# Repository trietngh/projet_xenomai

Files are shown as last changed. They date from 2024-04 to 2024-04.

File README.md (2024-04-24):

# Dumber

Depot du projet de temps reel 4eme année au departement GEI de l'INSA Toulouse.

## Repertoires
- hardware : contient les plans pour la partie mecanique du robot et de son chargeur, ainsi que les plans de conception des PCB du robot, du chargeur, de l'adaptateur Xbee pour la raspberry  et les plans des CAP du robot
- software: rassemble les parties logicielles du robot, du chargeur, les bibliotheques et superviseur coté raspberry et l'interface Web
- doc: contient les sujets de TD et TP
- aruco_markers: Script de generation des tags (aruco) utilisés sur les robots

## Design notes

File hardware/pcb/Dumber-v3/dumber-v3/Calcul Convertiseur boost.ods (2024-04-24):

Vout | 5
Vin | 3
Vsw | 0,5
Vdiode | 0,5
Fsw | 1600000
L1 | 0,00001
R2 | 13300
R1 | 40765,0406504065
DC | 0,6
Iload(objectif) | 1,5
Iind(Avg) | 3,75
Iripple | 0,09375
Isw | 3,796875
Iload(calc) | 1,5
Rled | 200
Cf | 6,50719483232995E-10

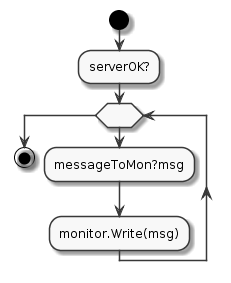
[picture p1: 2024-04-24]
doc/sujets/tex/rapport_etudiant/figures-pdf/th_sendToMon.png

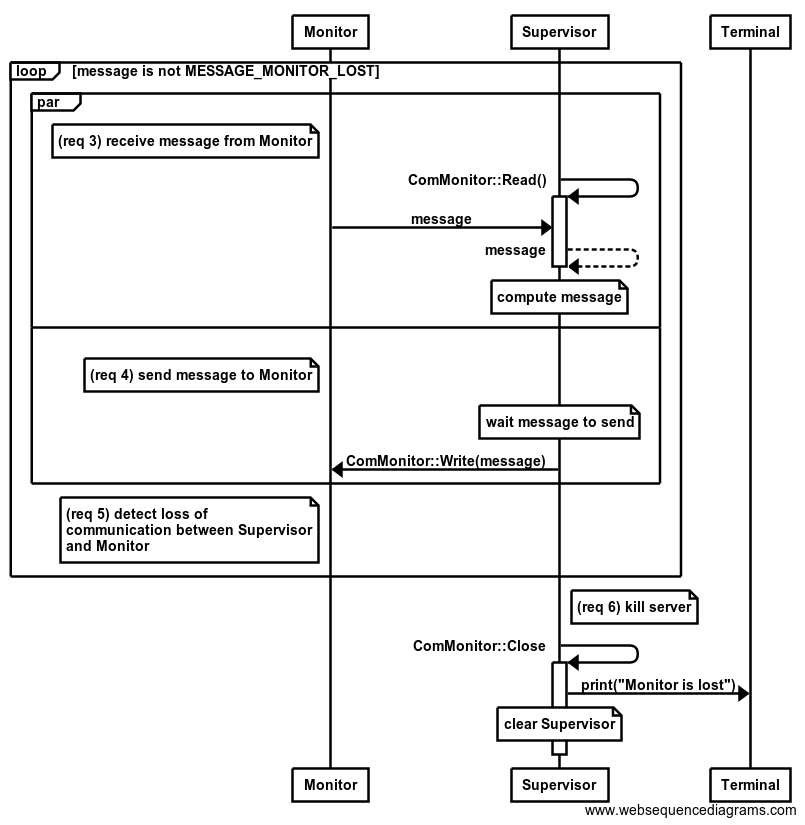
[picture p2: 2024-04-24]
doc/sujets/tex/specifications/seq_req/req3-6.png

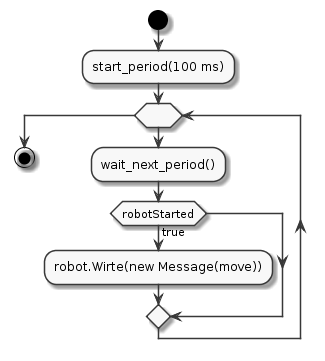
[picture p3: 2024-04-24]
doc/sujets/tex/conception/figures_pdf/activity/th_move.png

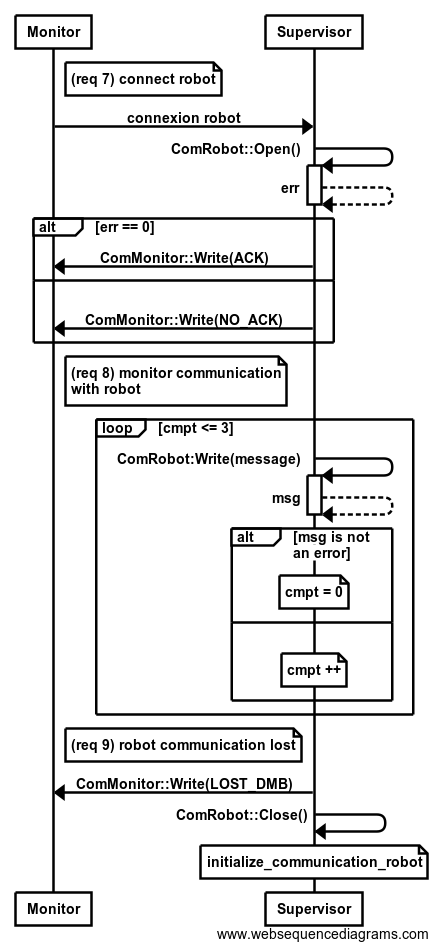
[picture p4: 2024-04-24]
doc/sujets/tex/specifications/seq_req/req7-9.png

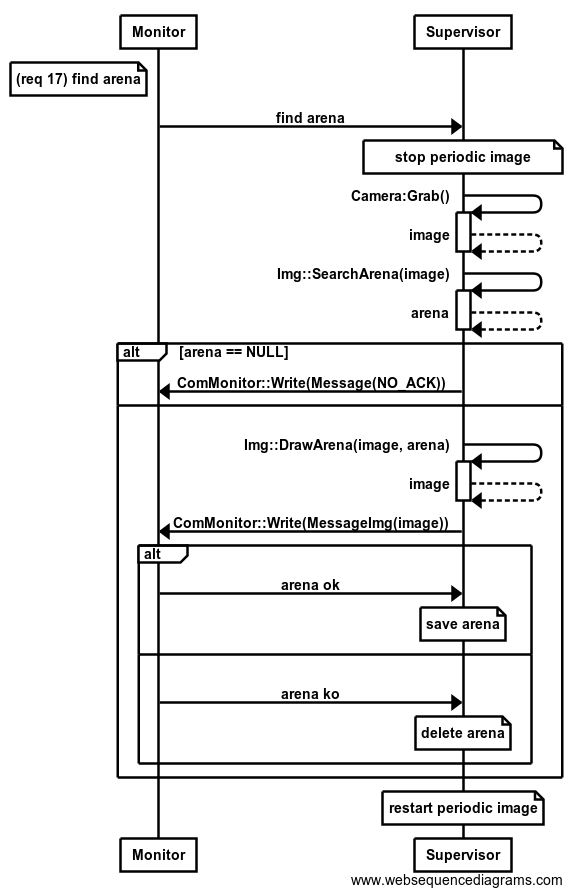
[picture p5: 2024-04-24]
doc/sujets/tex/specifications/seq_req/req17.png

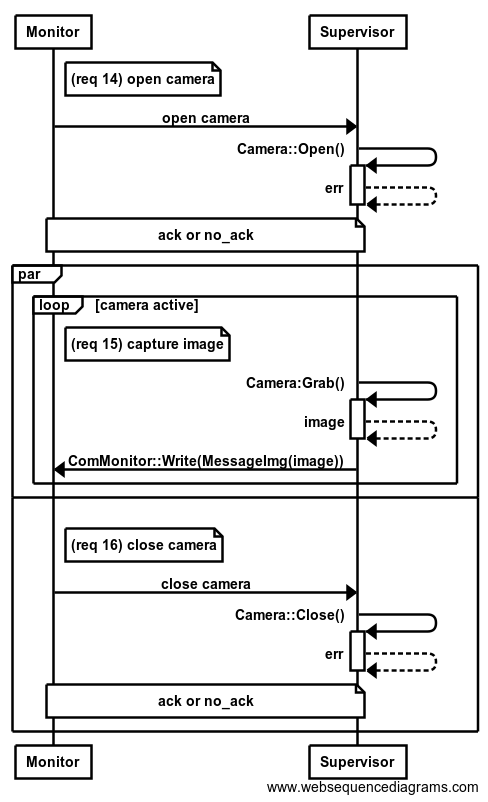
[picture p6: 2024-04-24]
doc/sujets/tex/specifications/seq_req/req14-16.png

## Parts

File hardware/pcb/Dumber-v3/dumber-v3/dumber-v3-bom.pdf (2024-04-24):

Source: /home/dimercur/Travail/git/dumber/hardware/pcb/Dumber-v3/dumber-v3/dumber-v3.kicad_sch Date: lun. 04 sept. 2023 10:56:20
Tool: Eeschema 7.0.7
Generator:/app/share/kicad/plugins/bom_csv_grouped_by_value.py
Component Count:70
Collated Components:
Item | Qty | Reference(s) | Value | LibPart | Footprint | Datasheet DNP
1 | 1 BT1 | Li-ION | Device:Battery_Cell | INSA:Battery-14500 | ~
2 | 2 C1, C4 | 10nF Device:C | Capacitor_SMD:C_0805_2012Metric ~
3 | 1 C2 | 68nF Device:C | Capacitor_SMD:C_0805_2012Metric ~
4 | 1 C3 | 100µF Device:C | Capacitor_SMD:C_1210_3225Metric ~
5 | 1 C5 | 2,20µF Device:C | Capacitor_SMD:C_0805_2012Metric ~
6 | 2 C6, C11 | 10µF Device:C | Capacitor_SMD:C_0805_2012Metric ~
7 | 4 C7, C12, C13, C22 | 1µF Device:C | Capacitor_SMD:C_0805_2012Metric ~
8 | 1 C8 | 650pF Device:C | Capacitor_SMD:C_0805_2012Metric ~
9 | 1 C9 | 100pF Device:C | Capacitor_SMD:C_0805_2012Metric ~
10 | 1 C10 | 10µF Device:C | Capacitor_SMD:C_1210_3225Metric ~
11 | 2 C14, C15 | 470nF Device:C | Capacitor_SMD:C_0805_2012Metric ~
12 | 4 C16, C17, C18, C19 | 100nF Device:C | Capacitor_SMD:C_0805_2012Metric ~
13 | 1 C21 | 1nF Device:C | Capacitor_SMD:C_0805_2012Metric ~
14 | 1 D1 | PMEG2020CPA | Device:D_Dual_CommonCathode_AAK_Parallel INSA:Nexperia_SOT-1061 | ~
15 | 1 D2 | FM5818-W | Device:D_Schottky | Diode_SMD:D_SMA | ~
16 | 3 H1, H2, H3 | MountingHole | Mechanical:MountingHole | MountingHole:MountingHole_3.2mm_M3_ISO14580 ~
17 | 2 J1, J2 | Conn_02x03_Odd_Even Connector_Generic:Conn_02x03_Odd_Even | Connector_IDC:IDC-Header_2x03_P2.54mm_Vertical ~
18 | 1 J3 | Conn_02x05_Odd_Even Connector_Generic:Conn_02x05_Odd_Even | Connector_PinHeader_1.27mm:PinHeader_2x05_P1.27mm_Horizontal ~
19 | 1 J4 | TE 1-84982-0 | Connector_Generic:Conn_01x10 | INSA:TE 1-84982-0 | ~
20 | 1 L1 | 10µH Device:L | Inductor_SMD:L_Bourns_SRP7028A_7.3x6.6mm ~
21 | 1 L2 | 5,6µH | Device:L | Inductor_SMD:L_1812_4532Metric | ~
22 | 2 M1, M2 | Motor | Insa:Motor | INSA:Motor Pololu HPCB with encoder
23 | 1 P1 | USB_C_Plug_GCT_USB4125 Insa:USB_C_Plug_GCT_USB4125 | INSA:USB_C_Receptacle_GCT_USB4125 https://www.usb.org/sites/default/files/documents/usb_type-c.zip
24 | 2 Q1, Q2 | PMN52XP | Insa:PMN52XP | Package_SO:TSOP-6_1.65x3.05mm_P0.95mm~
25 | 8 R1, R2, R4, R20, R24, R27, R28, R29 | 100K Device:R | Resistor_SMD:R_0805_2012Metric | ~
26 | 5 R3, R5, R7, R17, R18 | 1K Device:R | Resistor_SMD:R_0805_2012Metric | ~
27 | 2 R6, R26 | 10K Device:R | Resistor_SMD:R_0805_2012Metric | ~
28 | 1 R8 | 47K Device:R | Resistor_SMD:R_0805_2012Metric | ~
29 | 1 R9 | 470 Device:R | Resistor_SMD:R_0805_2012Metric | ~
30 | 1 R10 | 40,2K Device:R | Resistor_SMD:R_0805_2012Metric | ~
31 | 1 R11 | 13,3K Device:R | Resistor_SMD:R_0805_2012Metric | ~
32 | 2 R12, R14 | 15K Device:R | Resistor_SMD:R_0805_2012Metric | ~
33 | 1 R13 | 300 Device:R | Resistor_SMD:R_0805_2012Metric | ~
34 | 1 R19 | 150K Device:R | Resistor_SMD:R_0805_2012Metric | ~
35 | 1 R25 | 10R Device:R | Resistor_SMD:R_0805_2012Metric | ~
36 | 1 SW1 | SW_Push | Switch:SW_Push | Button_Switch_SMD:Panasonic_EVQPUJ_EVQPUA ~
37 | 1 U1 | XBEE-3 | Insa:XBEE-3 | INSA:XBEE-3-TH
38 | 1 U2 | STM32F071CBTx | MCU_ST_STM32F0:STM32F071CBTx | Package_QFP:LQFP-48_7x7mm_P0.5mm http://www.st.com/st-web-ui/static/active/en/resource/technical/document/datasheet/DM00098745.pdf
39 | 1 U3 | LTC2954-2 | Insa:LTC2954-2 | Package_TO_SOT_SMD:SOT-23-8
40 | 1 U4 | L6924U | Insa:L6924U | INSA:L6924UTR
41 | 1 U5 | LM2731XMF | Regulator_Switching:LM2731XMF | Package_TO_SOT_SMD:SOT-23-5 | http://www.ti.com/lit/ds/symlink/lm2731.pdf
42 | 1 U6 | AP2206 | Regulator_Linear:TC1186 | Package_TO_SOT_SMD:SOT-23-5 | http://ww1.microchip.com/downloads/en/DeviceDoc/21350E.pdf
43 | 1 U7 | A3909 | Insa:A3909 | Package_SO:SSOP-10_3.9x4.9mm_P1.00mm

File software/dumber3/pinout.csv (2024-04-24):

Position | Name | Type | Signal | Label | AF0 | AF1 | AF2 | AF3 | AF4 | AF5 | AF6
1 | PC0 | I/O | LPTIM1_IN1 | ENC_PHA_GAUCHE | LPTIM1_IN1 |  | EVENTOUT |  |  |  | LPUART1_RX
2 | PC13-ANTI_TAMP | I/O
3 | PC14-OSC32_IN | I/O
4 | PC15-OSC32_OUT | I/O
5 | PH0-OSC_IN | I/O
6 | PH1-OSC_OUT | I/O
7 | NRST | Reset
8 | VSSA | Power
9 | VDDA | Power
10 | PA0 | I/O | ADC_IN0 | BATTERY_SENSE |  | LPTIM1_IN1 | TIM2_CH1 |  | USART2_CTS | TIM2_ETR
11 | PA1 | I/O | TIM2_CH2 | PWM_B_GAUCHE | EVENTOUT | LPTIM1_IN2 | TIM2_CH2 | I2C1_SMBA | USART2_DE/USART2_RTS | TIM21_ETR
12 | PA2 | I/O | TIM21_CH1 | ENC_PHA_DROIT | TIM21_CH1 |  | TIM2_CH3 |  | USART2_TX |  | LPUART1_TX
13 | PA3 | I/O | TIM21_CH2 | ENC_PHB_DROIT | TIM21_CH2 |  | TIM2_CH4 |  | USART2_RX |  | LPUART1_RX
14 | PA4 | I/O |  |  | SPI1_NSS | LPTIM1_IN1 |  |  | USART2_CK
15 | PA5 | I/O | LPTIM1_IN2 | ENC_PHB_GAUCHE | SPI1_SCK | LPTIM1_IN2 | TIM2_ETR |  |  | TIM2_CH1
16 | PA6 | I/O |  |  | SPI1_MISO | LPTIM1_ETR |  |  | LPUART1_CTS |  | EVENTOUT
17 | PA7 | I/O |  |  | SPI1_MOSI | LPTIM1_OUT |  |  | USART2_CTS |  | EVENTOUT
18 | PB0 | I/O | TIM2_CH3 | PWM_A_DROIT | EVENTOUT | SPI1_MISO |  |  | USART2_DE/USART2_RTS | TIM2_CH3
19 | PB1 | I/O | TIM2_CH4 | PWM_B_DROIT | USART2_CK | SPI1_MOSI |  |  | LPUART1_DE/LPUART1_RTS | TIM2_CH4
20 | PB2 | I/O |  |  |  |  | LPTIM1_OUT
21 | PB10 | I/O | LPUART1_TX |  |  |  | TIM2_CH3 |  |  |  | LPUART1_TX
22 | PB11 | I/O | LPUART1_RX |  | EVENTOUT |  | TIM2_CH4 |  |  |  | LPUART1_RX
23 | VSS | Power
24 | VDD | Power
25 | PB12 | Output | GPIO_Output | LED_ROUGE | SPI1_NSS |  |  |  |  |  | EVENTOUT
26 | PB13 | Output | GPIO_Output | LED_ORANGE | SPI1_SCK |  | RCC_MCO |  |  | TIM21_CH1 | LPUART1_CTS
27 | PB14 | Output | GPIO_Output | LED_VERTE | SPI1_MISO |  | RTC_OUT_ALARM/RTC_OUT_CALIB |  |  | TIM21_CH2 | LPUART1_DE/LPUART1_RTS
28 | PB15 | Output | GPIO_Output | SHUTDOWN_ENCODERS | SPI1_MOSI |  | RTC_REFIN
29 | PA8 | I/O | TIM2_CH1 | PWM_A_GAUCHE | RCC_MCO |  | LPTIM1_IN1 | EVENTOUT | USART2_CK | TIM2_CH1
30 | PA9 | I/O |  |  | RCC_MCO | I2C1_SCL |  |  | USART2_TX
31 | PA10 | I/O |  |  |  | I2C1_SDA |  |  | USART2_RX
32 | PA11 | I/O |  |  | SPI1_MISO |  | EVENTOUT |  | USART2_CTS | TIM21_CH2
33 | PA12 | I/O |  |  | SPI1_MOSI |  | EVENTOUT |  | USART2_DE/USART2_RTS
34 | PA13 | I/O | SYS_SWDIO |  | SYS_SWDIO | LPTIM1_ETR |  |  |  |  | LPUART1_RX
35 | VSS | Power
36 | VDD | Power
37 | PA14 | I/O | SYS_SWCLK |  | SYS_SWCLK | LPTIM1_OUT |  | I2C1_SMBA | USART2_TX |  | LPUART1_TX
38 | PA15 | I/O |  |  | SPI1_NSS |  | TIM2_ETR | EVENTOUT | USART2_RX | TIM2_CH1
39 | PB3 | I/O | GPIO_EXTI3 | BUTTON_SENSE | SPI1_SCK |  | TIM2_CH2 |  | EVENTOUT
40 | PB4 | I/O | GPIO_EXTI4 | USB_SENSE | SPI1_MISO |  | EVENTOUT
41 | PB5 | I/O |  |  | SPI1_MOSI |  | LPTIM1_IN1 | I2C1_SMBA
42 | PB6 | Input | GPIO_Input | CHARGER_ST2 | USART2_TX | I2C1_SCL | LPTIM1_ETR |  |  | TIM21_CH1
43 | PB7 | Input | GPIO_Input | CHARGER_ST1 | USART2_RX | I2C1_SDA | LPTIM1_IN2
44 | BOOT0 | Boot
45 | PB8 | Output | GPIO_Output | SHUTDOWN_5V |  |  |  |  | I2C1_SCL
46 | PB9 | Output | GPIO_Output | SHUTDOWN |  |  | EVENTOUT |  | I2C1_SDA
47 | VSS | Power
48 | VDD | Power

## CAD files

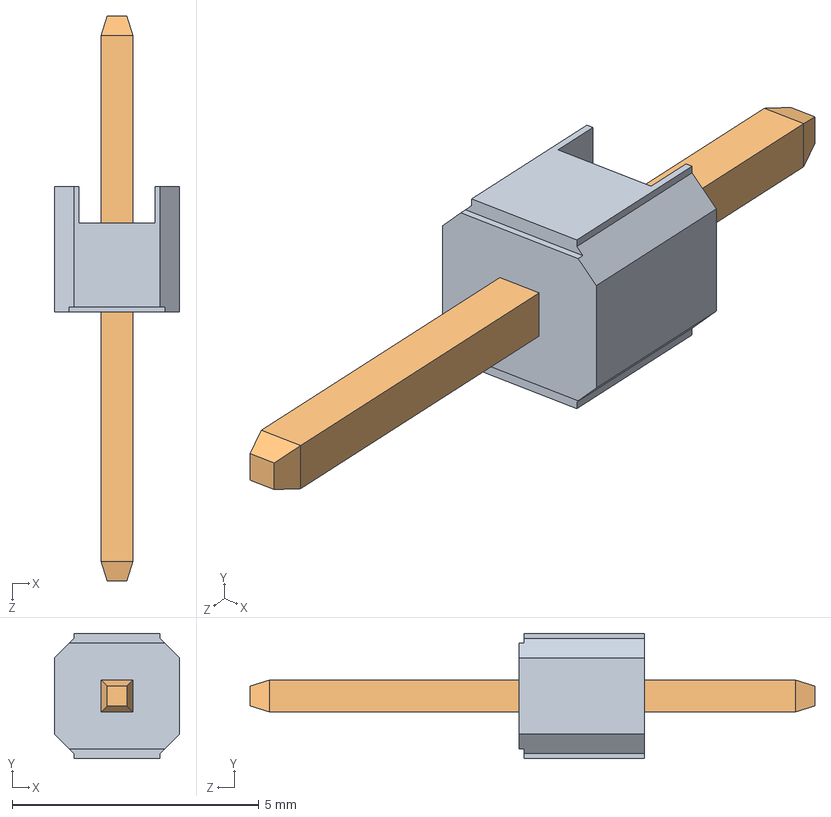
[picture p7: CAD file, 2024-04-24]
hardware/meca/Bibliotheque/headers/2.54_straight-header.SLDASM
2.54 x 2.54 x 11.4 mm
2.54_base
2.54_straight-pin

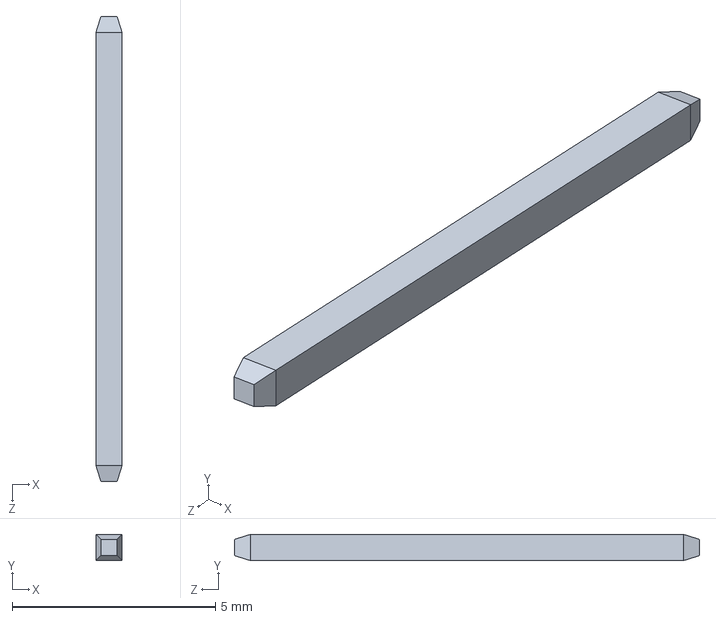
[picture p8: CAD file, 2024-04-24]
hardware/meca/Bibliotheque/headers/2.54_straight-pin.SLDPRT
0.65 x 0.65 x 11.4 mm

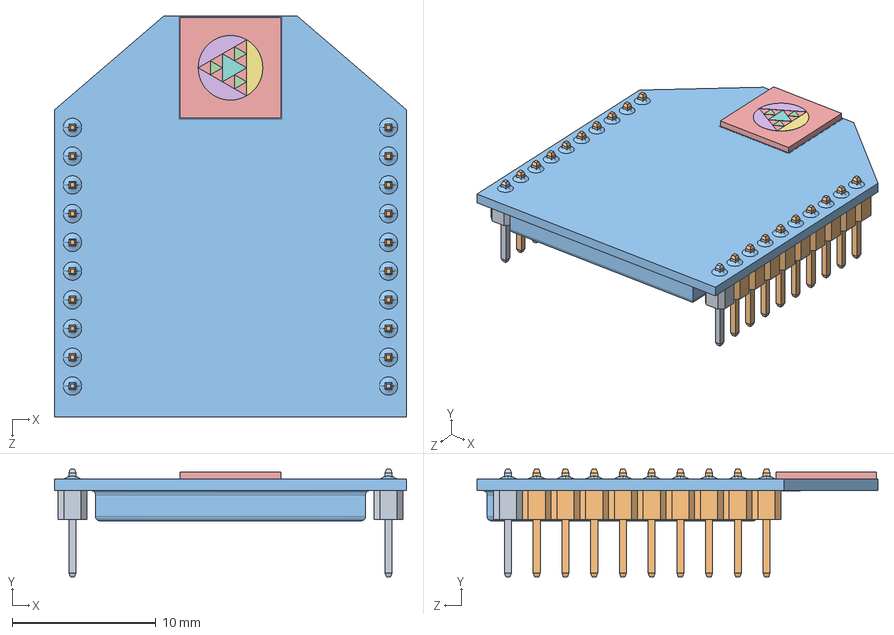
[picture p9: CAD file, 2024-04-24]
hardware/meca/Bibliotheque/XBee Chip.STEP
24.5 x 7.50 x 27.9 mm
User Library-XBee-Chip_XBee-10pin-male_1 x 2
User Library-XBee-Chip_XBee-Chip_1
User Library-XBee-Chip_XBee-Chip-antenna_1

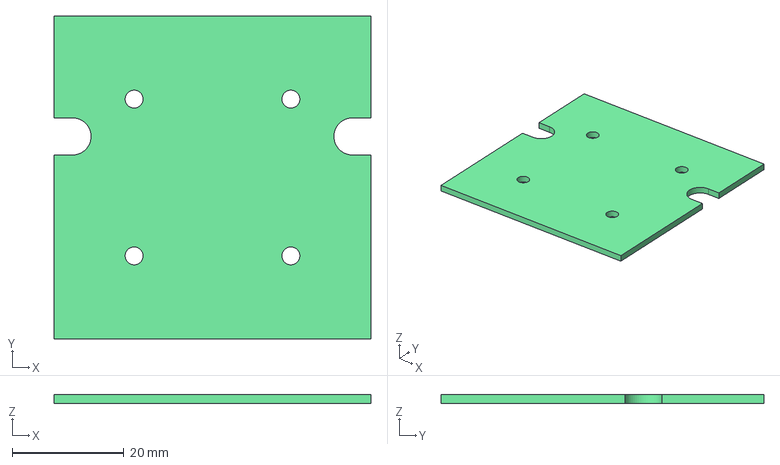
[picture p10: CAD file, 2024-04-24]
hardware/meca/Chargeur/1593K PCB.stp
56.6 x 57.7 x 1.60 mm

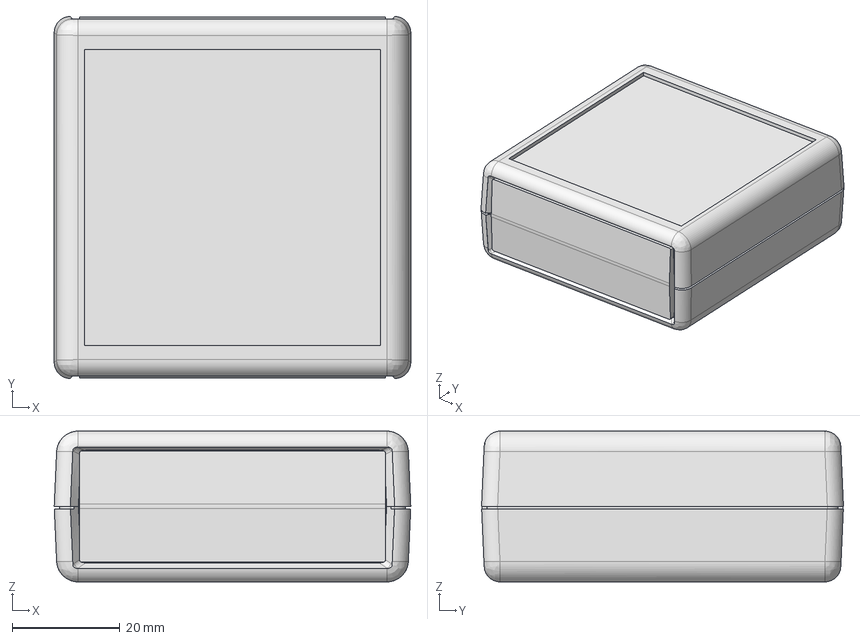
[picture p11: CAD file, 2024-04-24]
hardware/meca/Chargeur/Hammond/1593K.stp
66.2 x 67.2 x 28.0 mm
1593K BOTTOM
1593K Top
1593K-L-P-Q-X-Y Flat endplate x 2
1593K-L-P-Q-X-Y Contoured Endplate x 2
1593K PCB

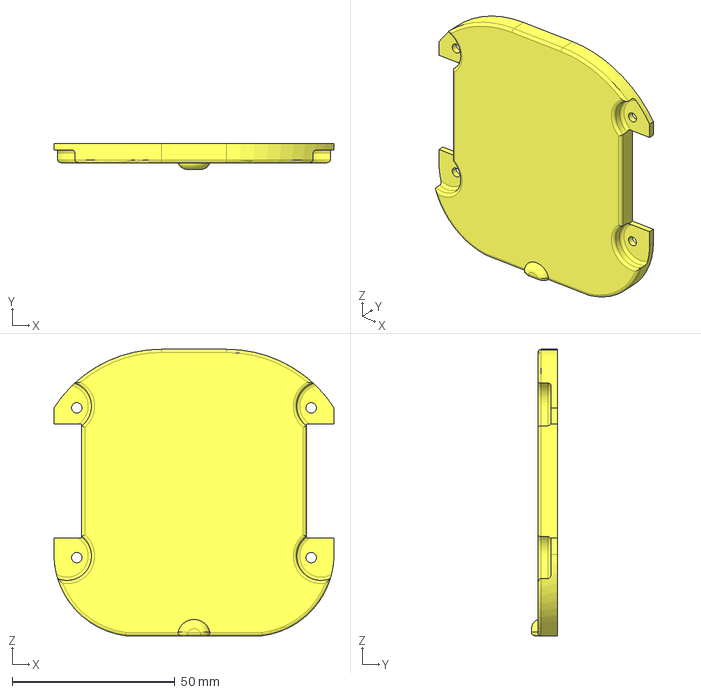
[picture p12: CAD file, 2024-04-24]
hardware/meca/coque_inf.stp
86.0 x 8.00 x 88.0 mm

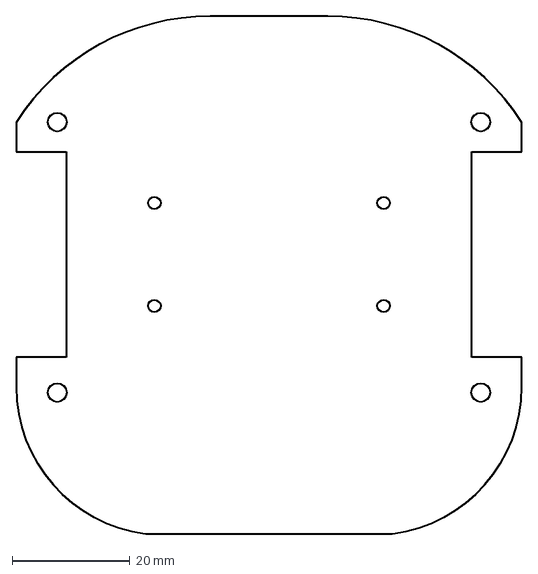
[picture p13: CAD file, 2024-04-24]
hardware/meca/Dumber_2022/export/pcb-tole.dxf
86.0 x 88.0 mm

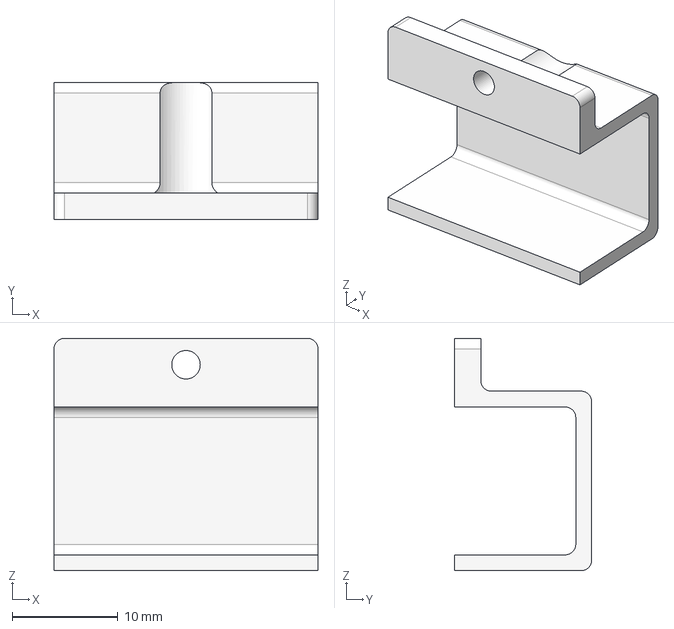
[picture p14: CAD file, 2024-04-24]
hardware/meca/Export/capot.stp
25.0 x 13.0 x 22.0 mm

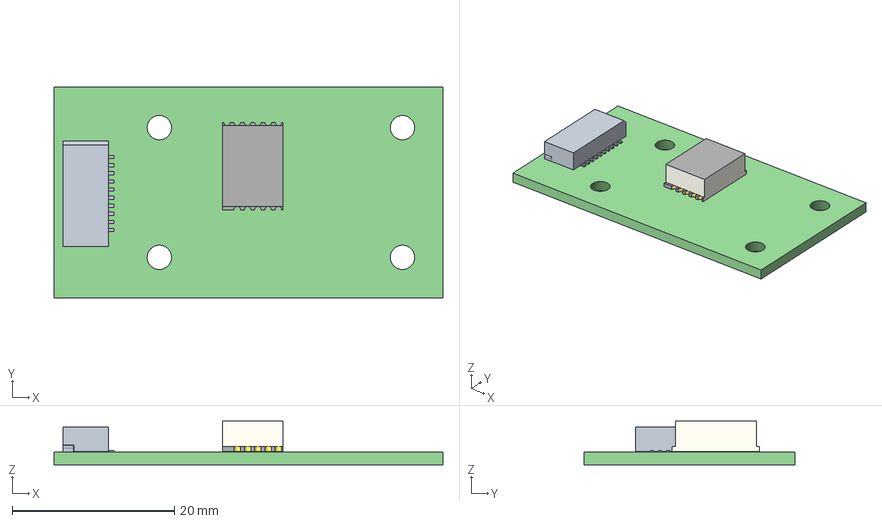
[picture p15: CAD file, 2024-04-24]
hardware/pcb/Dumber-v3/ecran/ecran/ecran.step
48.0 x 26.0 x 5.40 mm
ecran PCB

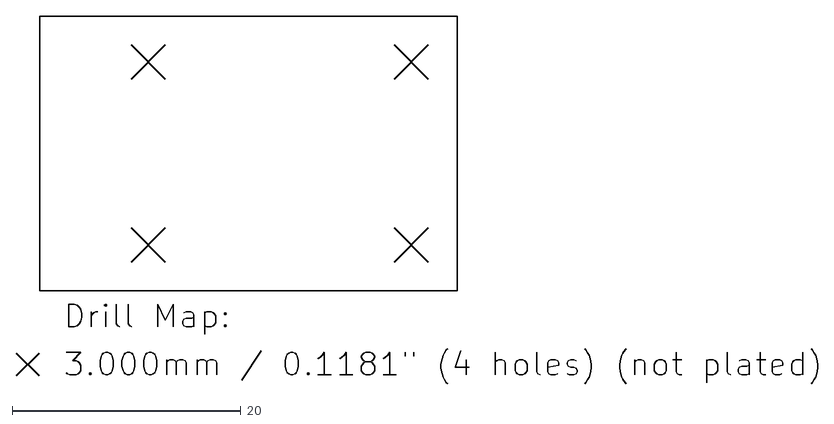
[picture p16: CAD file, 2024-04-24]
hardware/pcb/Dumber-v3/ecran/ecran/Gerber/ecran-NPTH-drl_map.dxf
70.1 x 32.1

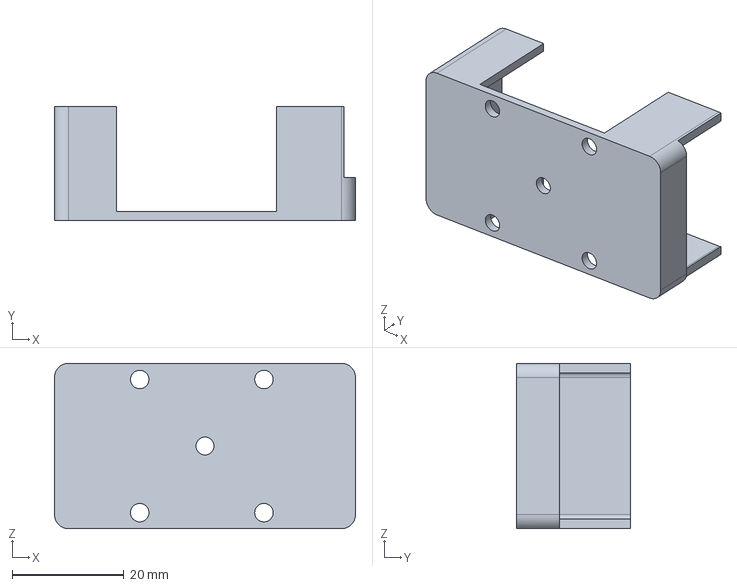
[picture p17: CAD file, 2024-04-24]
hardware/pcb/Models/Batterie.stp
53.8 x 20.3 x 29.6 mm

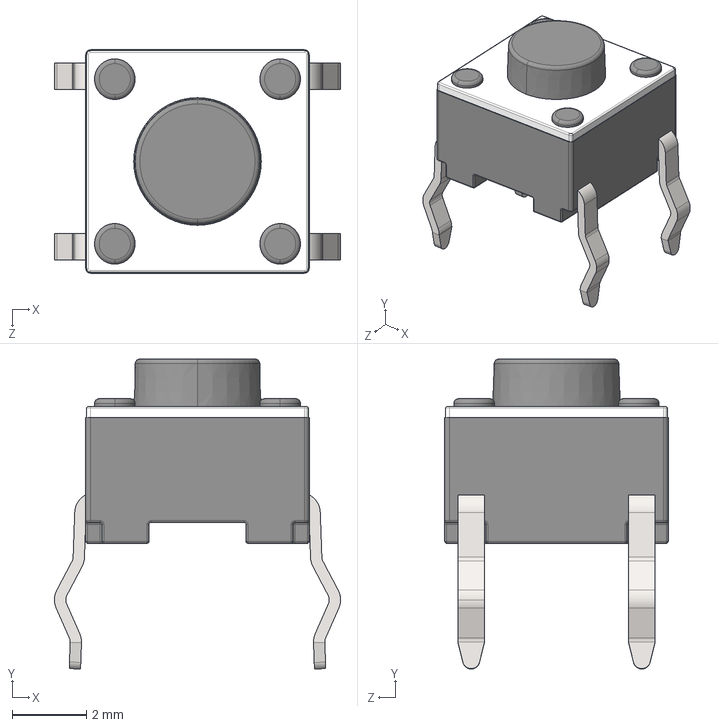
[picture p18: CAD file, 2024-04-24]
hardware/meca/Bibliotheque/tactileswitch-short.STEP
7.69 x 8.33 x 6.01 mm

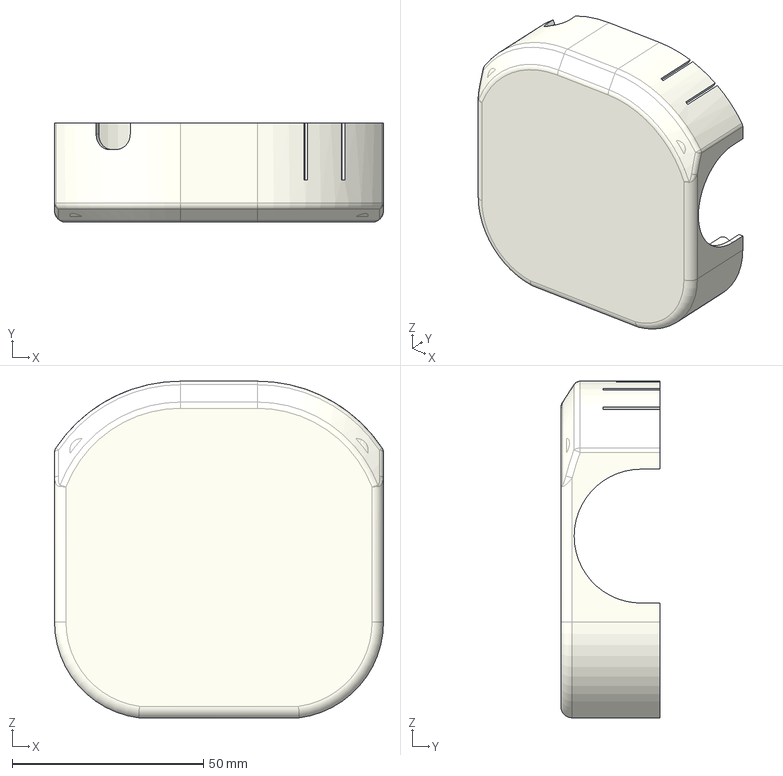
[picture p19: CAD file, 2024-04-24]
hardware/meca/coque_sup.stp
86.0 x 26.0 x 88.0 mm

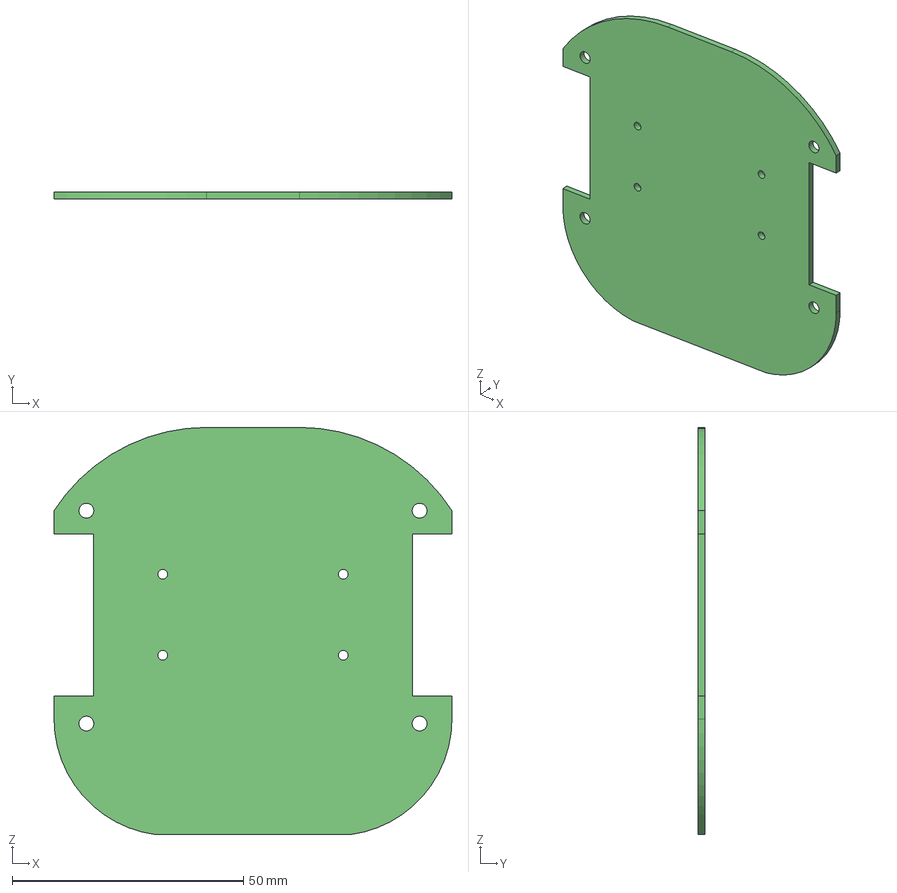
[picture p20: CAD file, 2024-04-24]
hardware/meca/Dumber_2022/export/pcb.stp
86.0 x 1.60 x 88.0 mm

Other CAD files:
hardware/meca/Export/pied.stp
hardware/pcb/Dumber-v3/ecran/ecran/Gerber/ecran-PTH-drl_map.dxf
hardware/pcb/Models/Bloc roue.stp
hardware/meca/Bibliotheque/headers/original.stl
hardware/meca/Bibliotheque/0605-LED_Verde.STEP
hardware/meca/Bibliotheque/Batterie.ipt
hardware/meca/Bibliotheque/Bloc roue.iam
hardware/meca/Bibliotheque/Platine encodeur.ipt
hardware/meca/Bibliotheque/Pneu.ipt
hardware/meca/Bibliotheque/Push Button Switch.STEP
hardware/meca/Bibliotheque/Robot.iam
hardware/meca/Bibliotheque/Roue.ipt
hardware/meca/Bibliotheque/USB_Mini_B_SMD_buchse.STEP
hardware/meca/Bibliotheque/axe.ipt
hardware/meca/Bibliotheque/capot.ipt
hardware/meca/Bibliotheque/connecteur 10.ipt
hardware/meca/Bibliotheque/connecteur 6.ipt
hardware/meca/Bibliotheque/fixation moteur.ipt
hardware/meca/Bibliotheque/helice encodeur.ipt
hardware/meca/Bibliotheque/mini usbl.ipt
hardware/meca/Bibliotheque/moteur.iam
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

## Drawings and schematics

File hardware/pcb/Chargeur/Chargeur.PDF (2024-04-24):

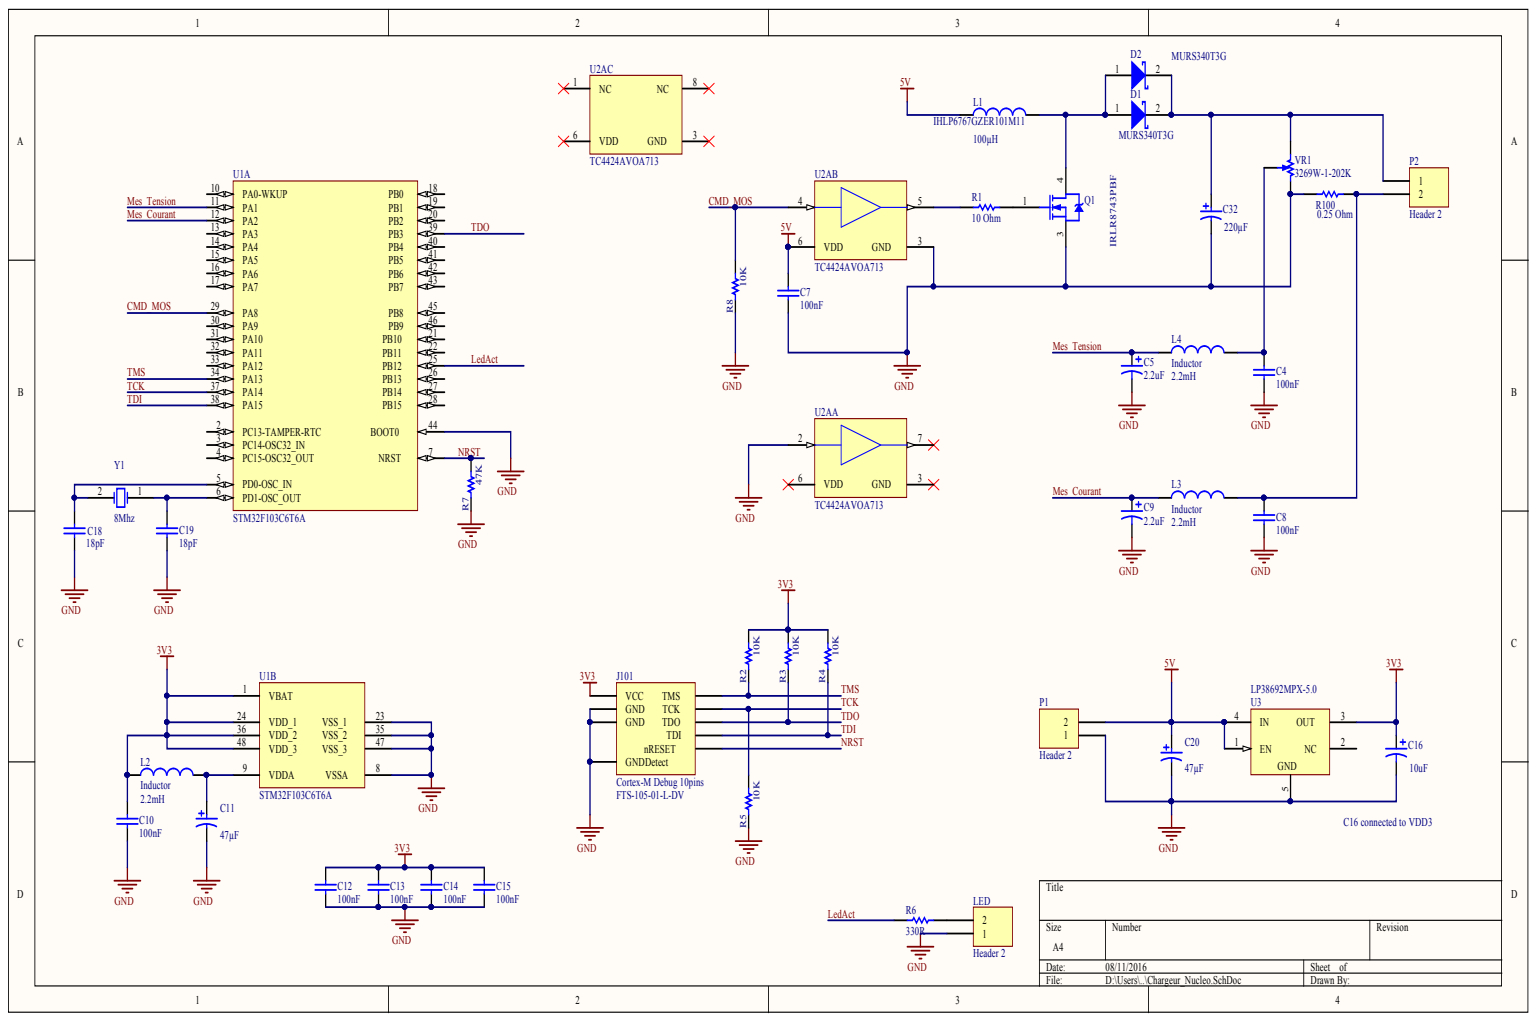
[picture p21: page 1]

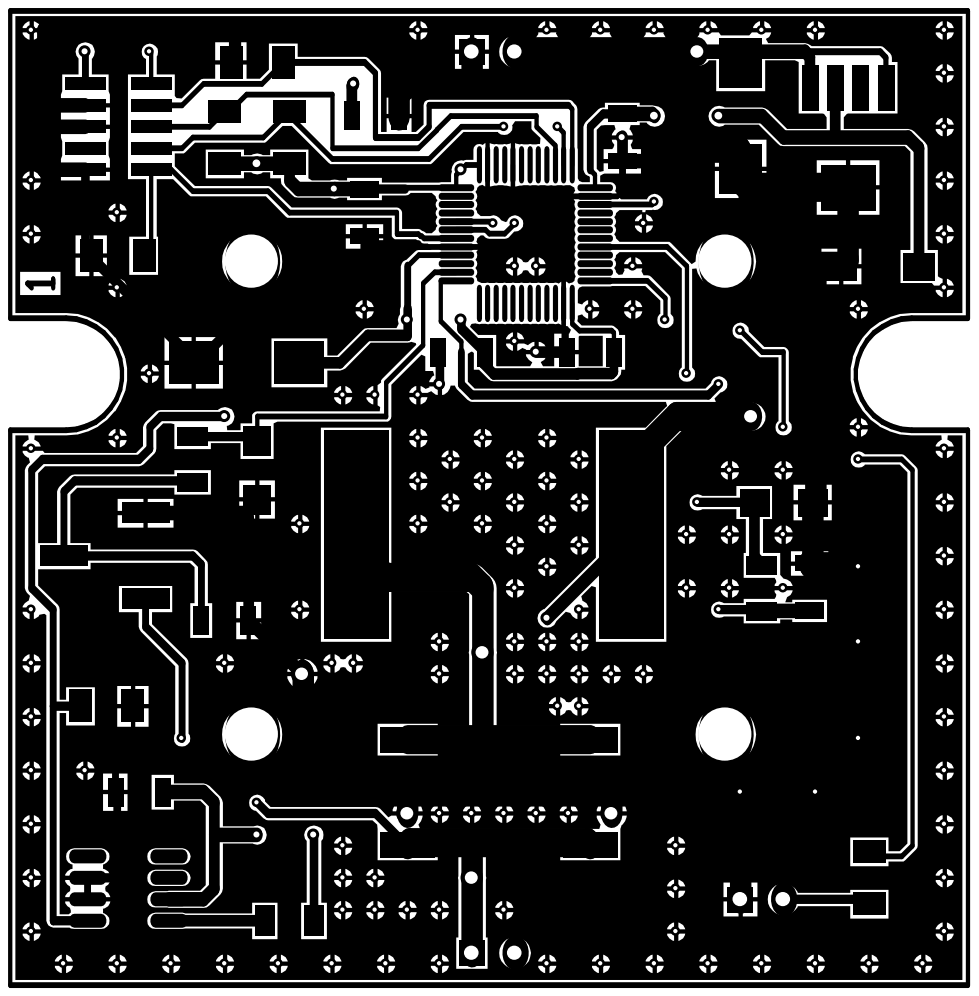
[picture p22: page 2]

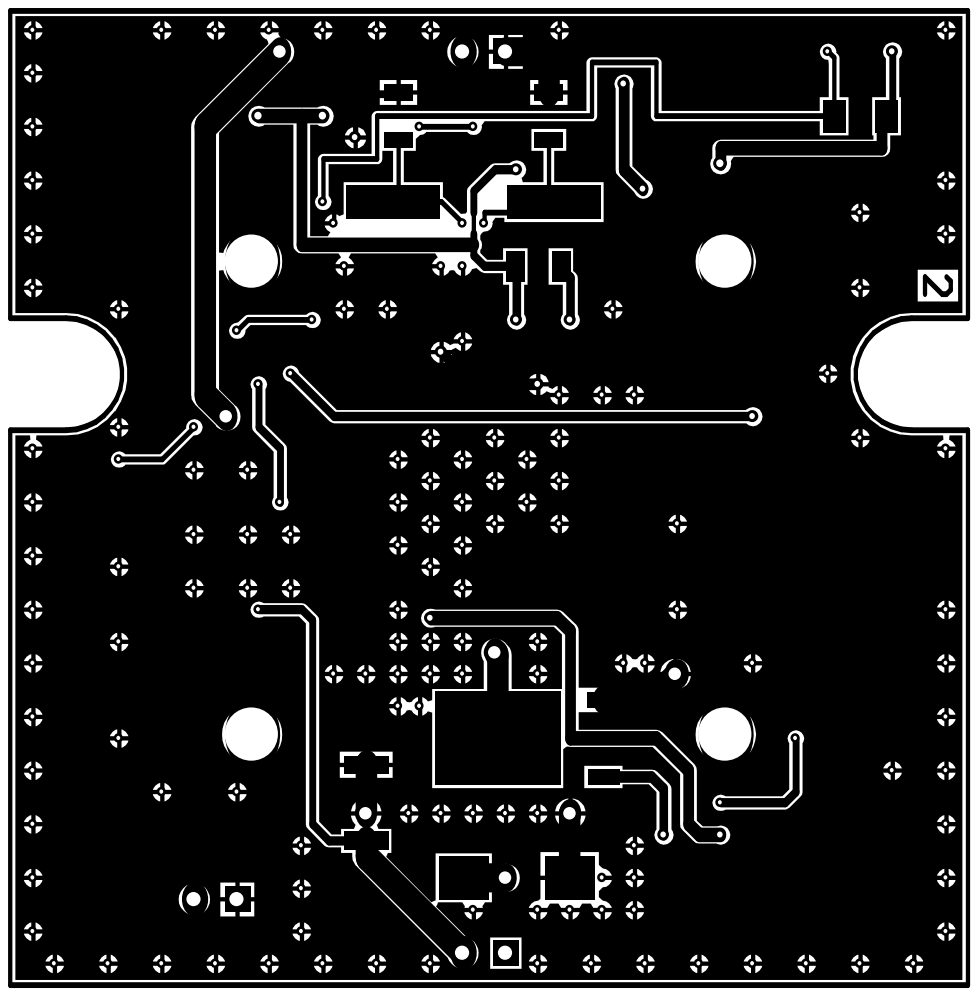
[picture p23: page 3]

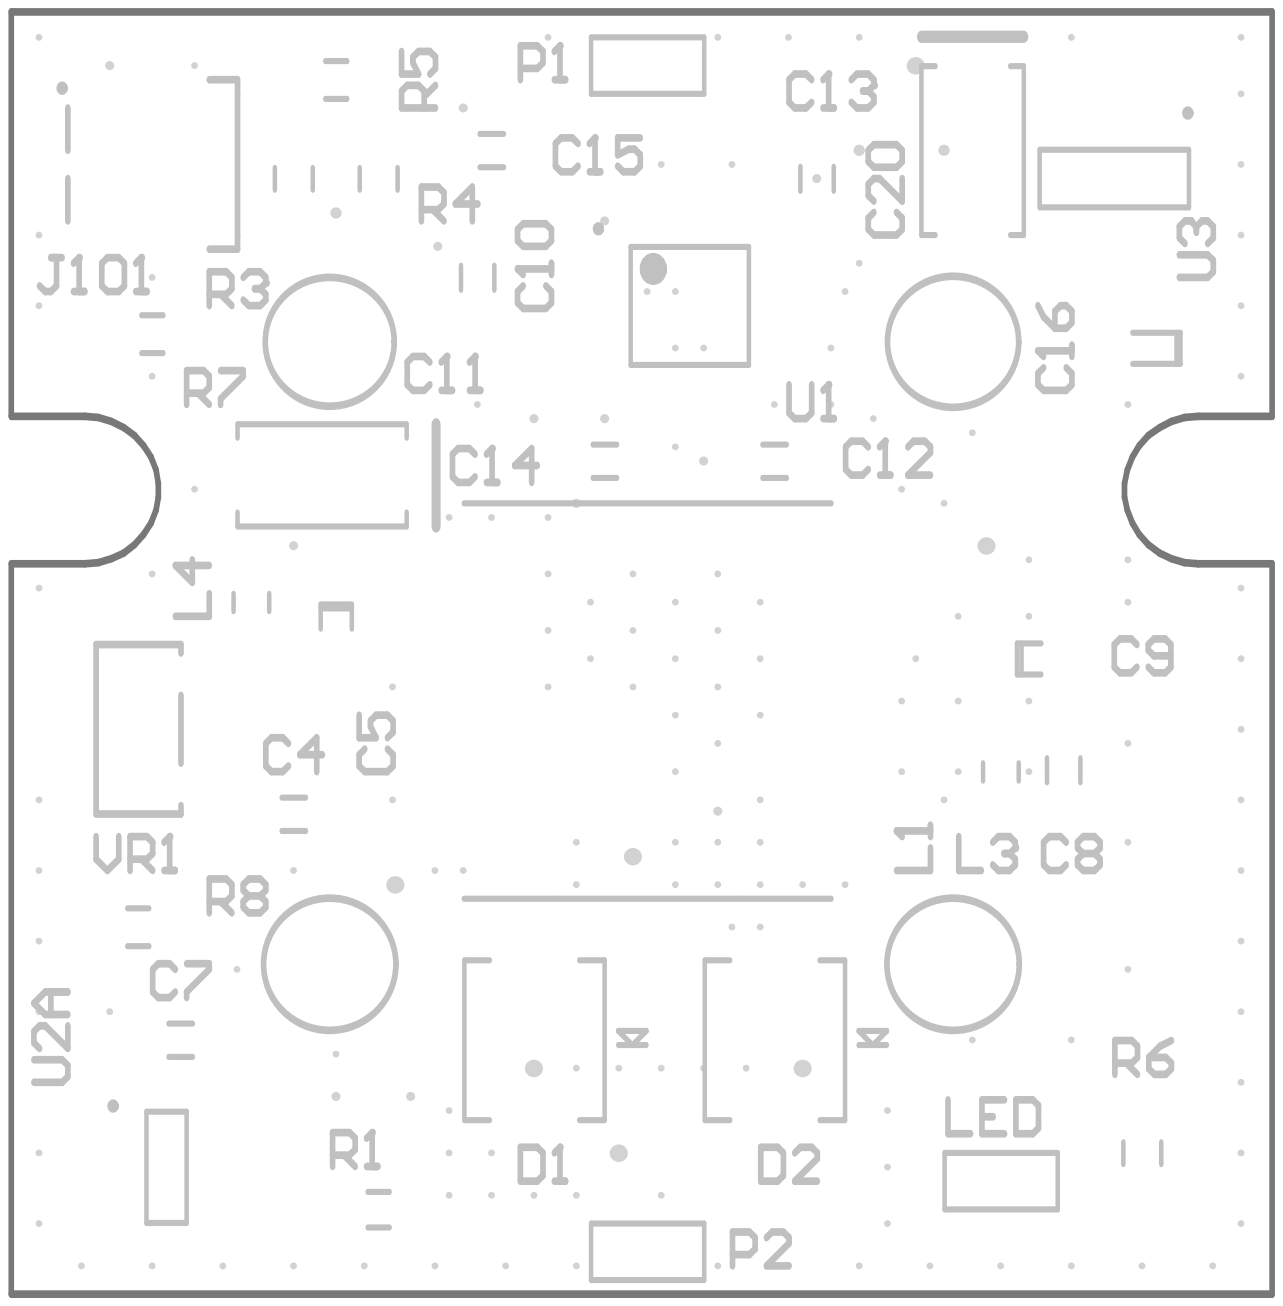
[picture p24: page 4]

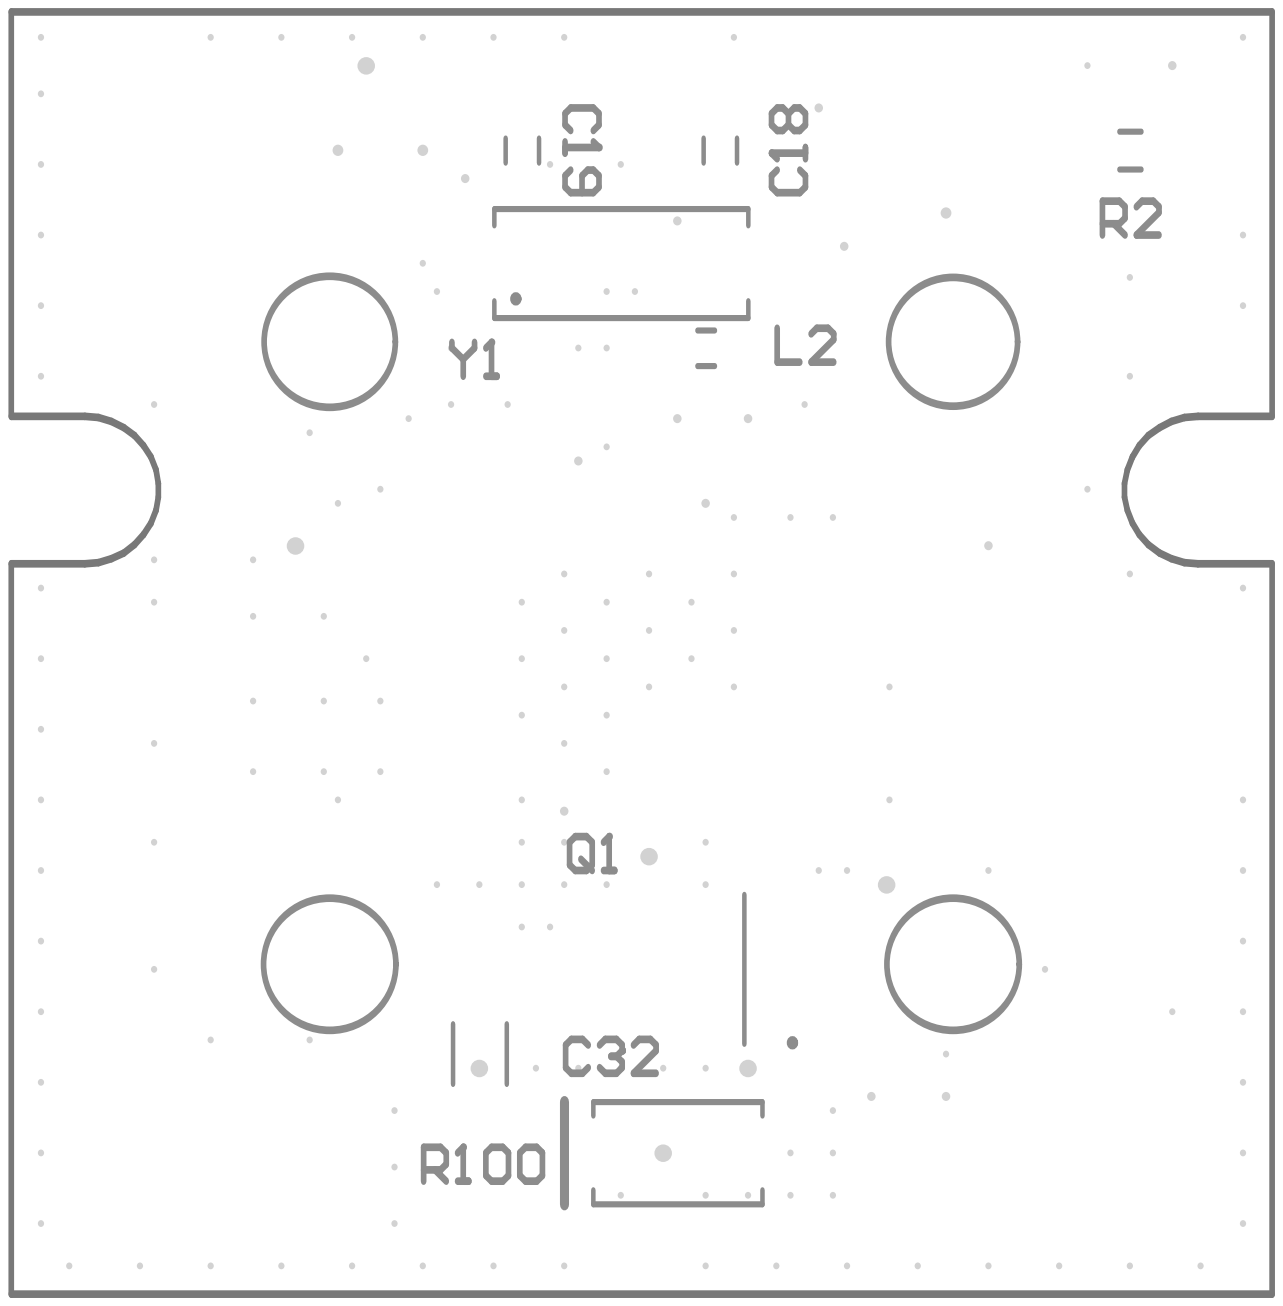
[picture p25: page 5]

Designator | Description | Value | Quantity
C4, C7, C8, C10, C12, C13, C14, C15 | CAP 100nF 25V ±10% 1206 (3216 Metric) Thickness 1mm SMD | 100nF | 8
C5, C9 | Conformal Coated Solid Tantalum Chip Capacitor: Standard Range, 4.7uF, 20% Tolerance, 4 WVDC @ -55°C to +85°C, Surge = 5V | 2.2uF | 2
C11, C20 | Tantalum Capacitor, 47 uF, +/- 10%, 16 V, -55 to 125 degC, 2917 (7343 Metric), RoHS, Tape and Reel | 47µF | 2
C16 | Midget Conformal Coated Solid Tantalum Chip Capacitor: 3.3uF, 20% Tolerance, 15 WVDC @ +85°C, Surge = 20V | 10uF | 1
C18, C19 | CAP 100nF 25V ±10% 1206 (3216 Metric) Thickness 1mm SMD | 18pF | 2
C32 | Tantalum Capacitor, 47 uF, +/- 10%, 16 V, -55 to 125 degC, 2917 (7343 Metric), RoHS, Tape and Reel | 220µF | 1
D1, D2 | High Voltage Surface Mount Schottky Rectifier, 3 A, -65 to 175 degC, 2-Pin SMD, RoHS, Tape and Reel | | 2
J101 | | | 1
L1 | Inductor | 100µH | 1
L2, L3, L4 | Inductor | 2.2mH | 3
LED, P1, P2 | Header, 2-Pin | | 3
Q1 | HEXFET Power MOSFET | | 1
R1 | 470R 0.25W 5% 1206 (3216 Metric) SMD | 10 Ohm | 1
R2, R3, R4, R5, R8 | 10K 0.25W 5% 1206 (3216 Metric) SMD | 10K | 5
R6 | 10K 0.25W 5% 1206 (3216 Metric) SMD | 330R | 1
R7 | 10K 0.25W 5% 1206 (3216 Metric) SMD | 47K | 1
R100 | 1R 0.75W 5% 2010 (5025 Metric) SMD | 0.25 Ohm | 1
U1 | ARM Cortex-M3 32-bit MCU, 32 KB Flash, 10 KB Internal RAM, 37 I/Os, 48-pin LQFP, -40 to 85 degC, Tray | | 1
U2A | 3A Dual High-Speed Power MOSFET Drivers, Non Inverting, Extended Temperature, Tape and Reel | | 1
U3 | 1A Low Dropout CMOS Linear Regulators, Stable with Ceramic Output Capacitors, 5-pin SOT-223 | | 1
VR1 | Square Trimming Potentiometer | | 1
Y1 | Surface Mount Quartz Crystal | 8Mhz | 1

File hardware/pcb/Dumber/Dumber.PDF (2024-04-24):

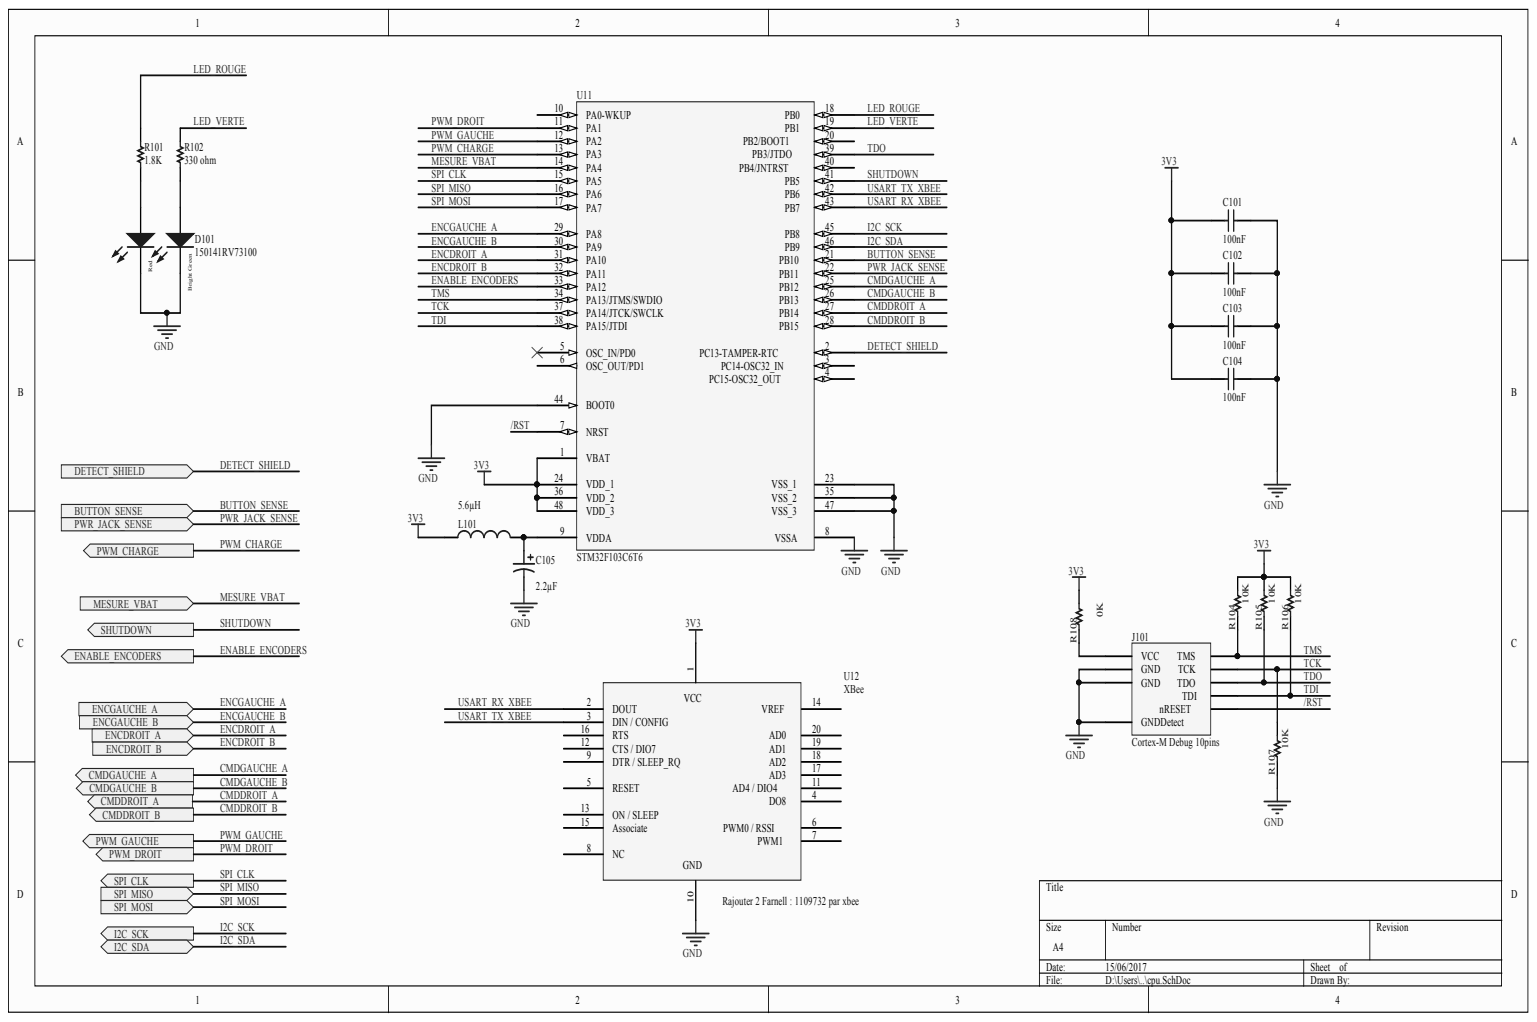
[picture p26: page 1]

3 6 | 3 5
4 8 | 4 7

TMS TCK TDI TDO /RST

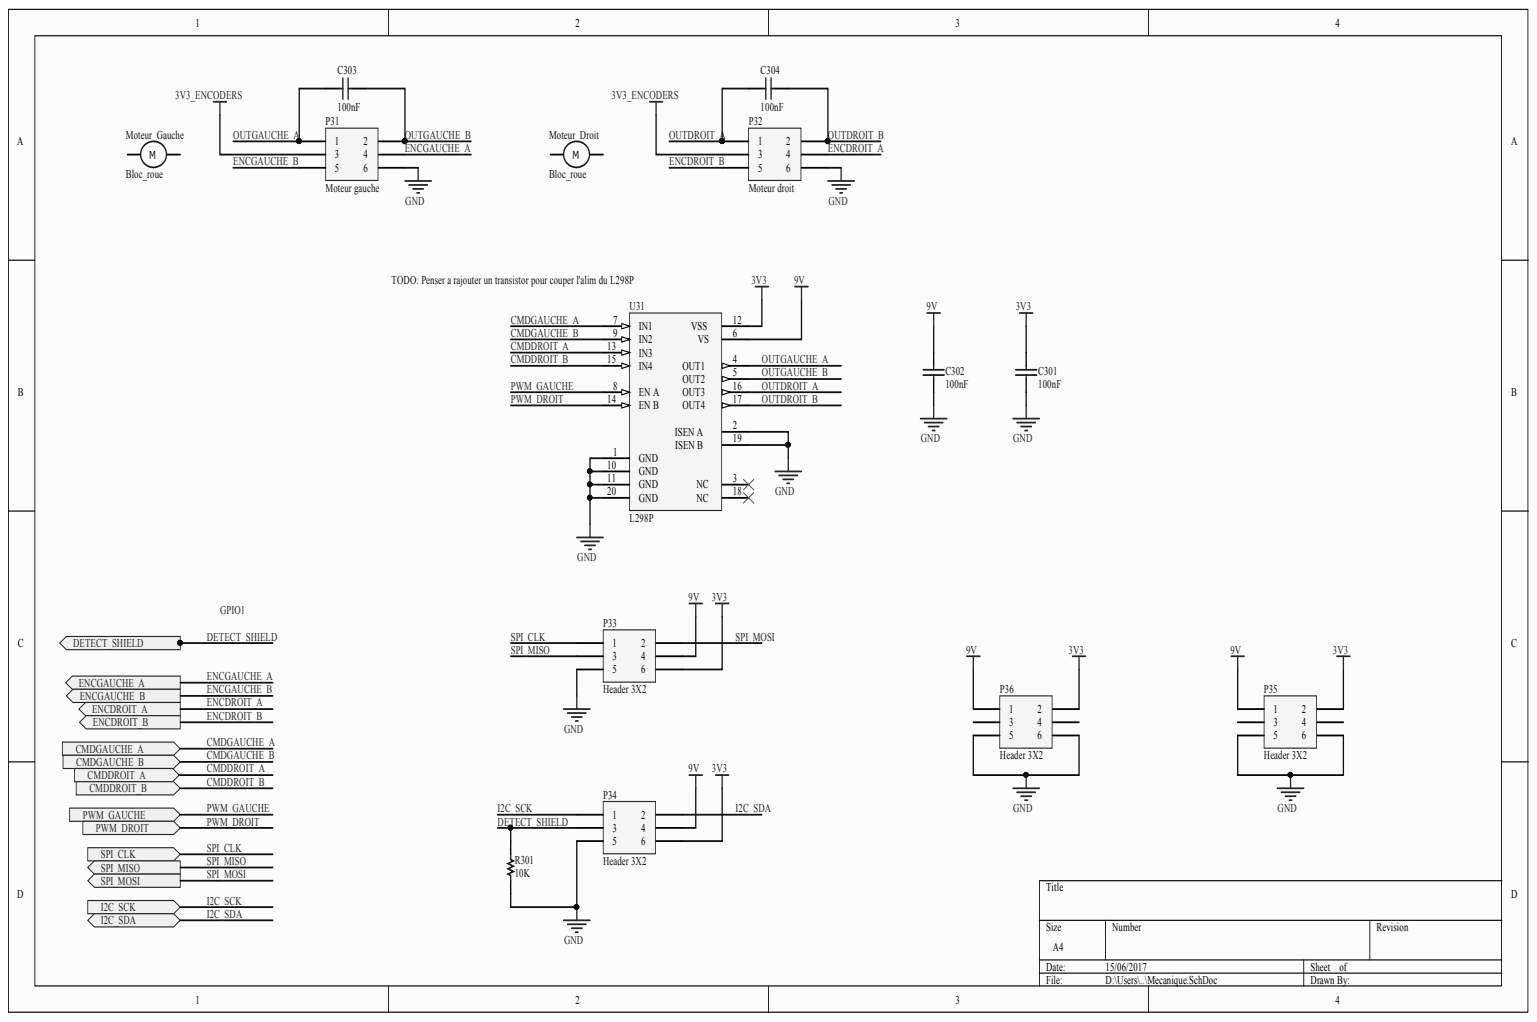
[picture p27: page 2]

TODO: Penser a rajouter un transistor pour couper l'alim du L298P

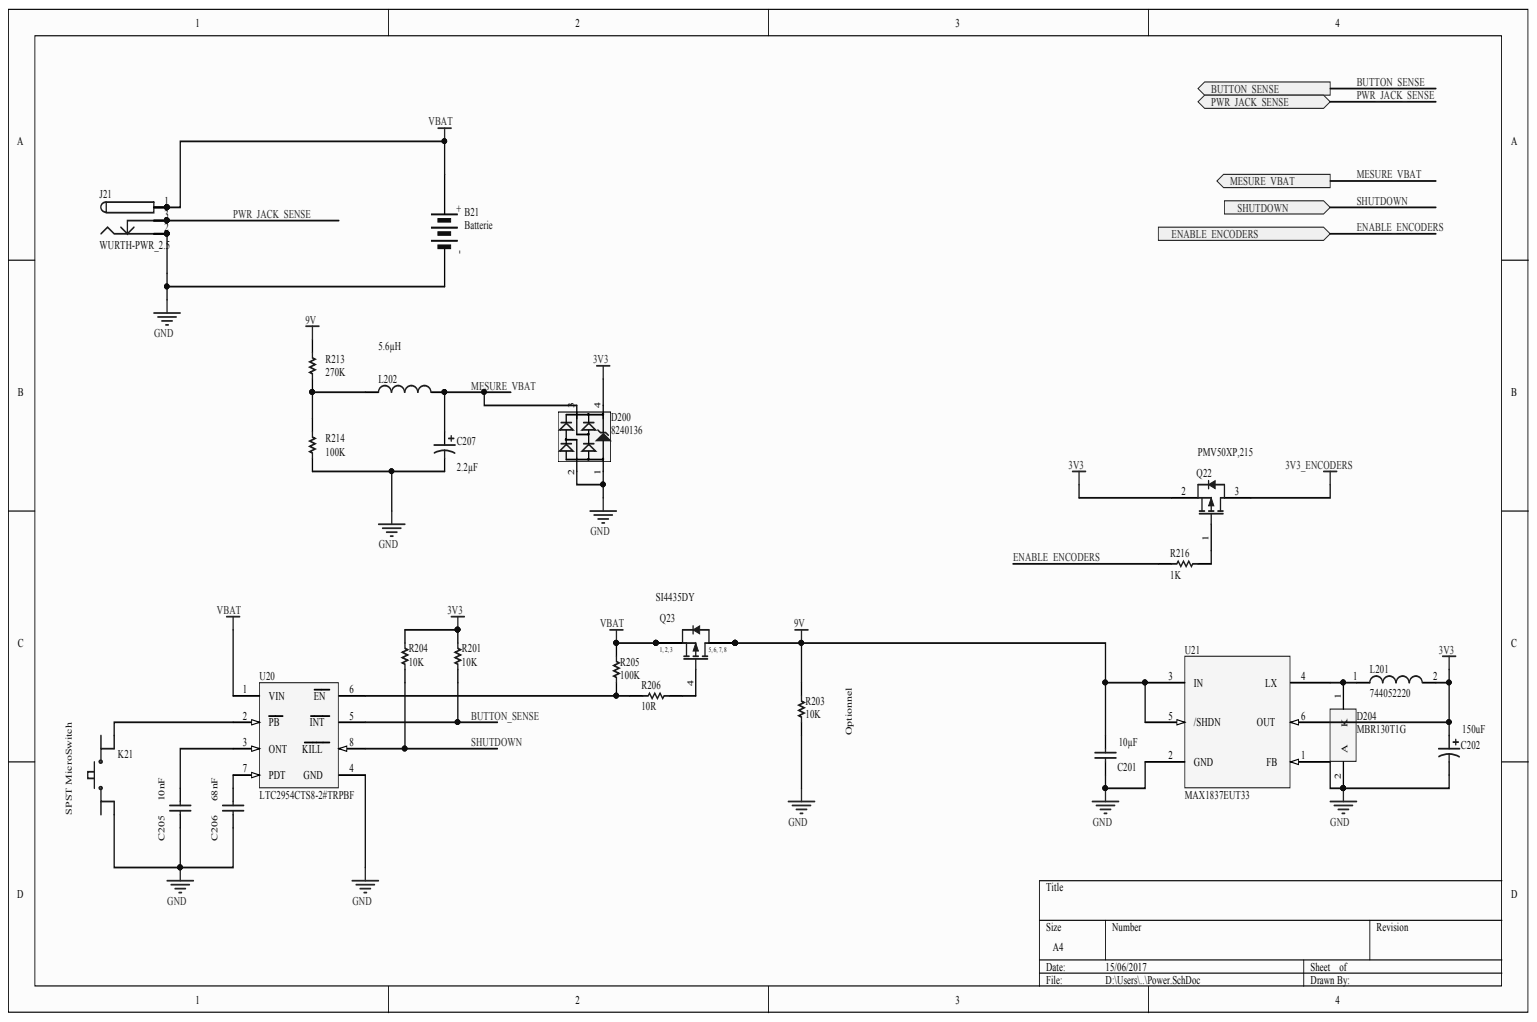
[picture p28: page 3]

PDT 7

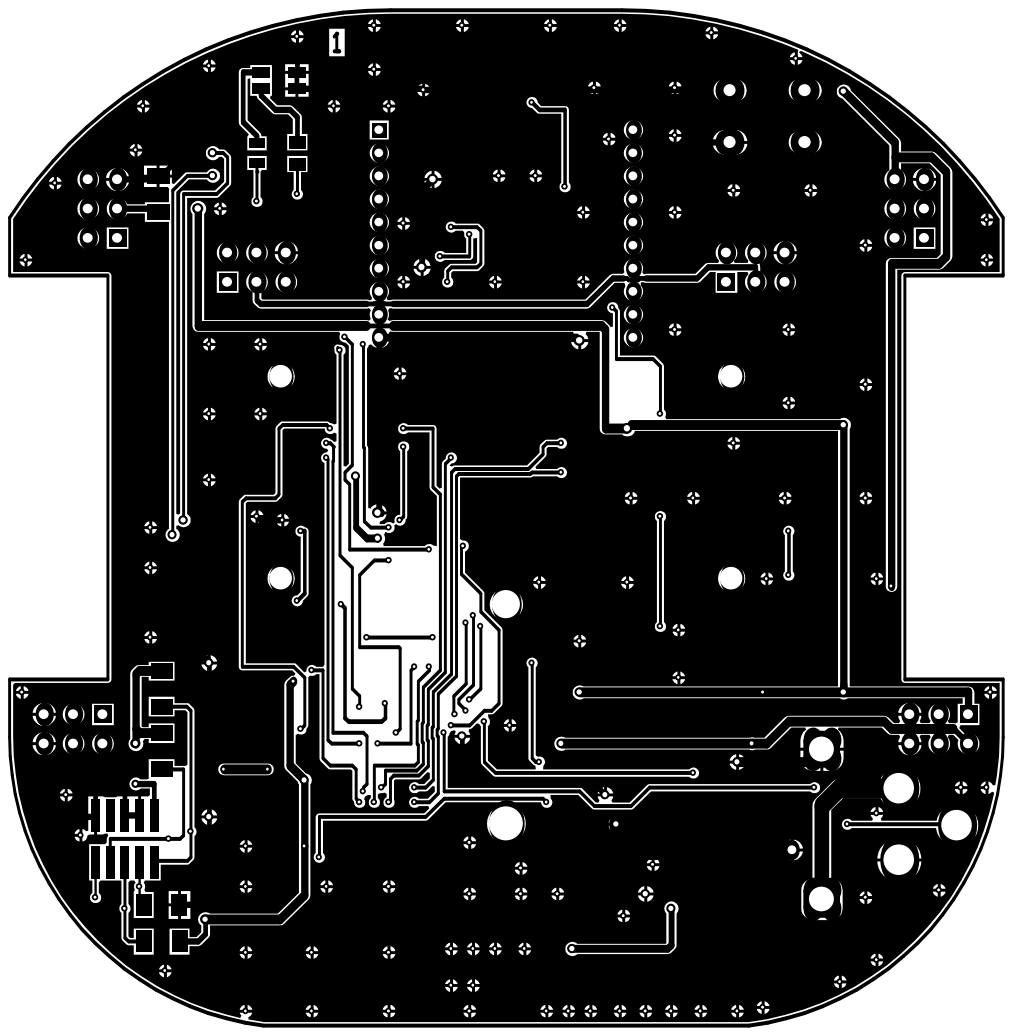
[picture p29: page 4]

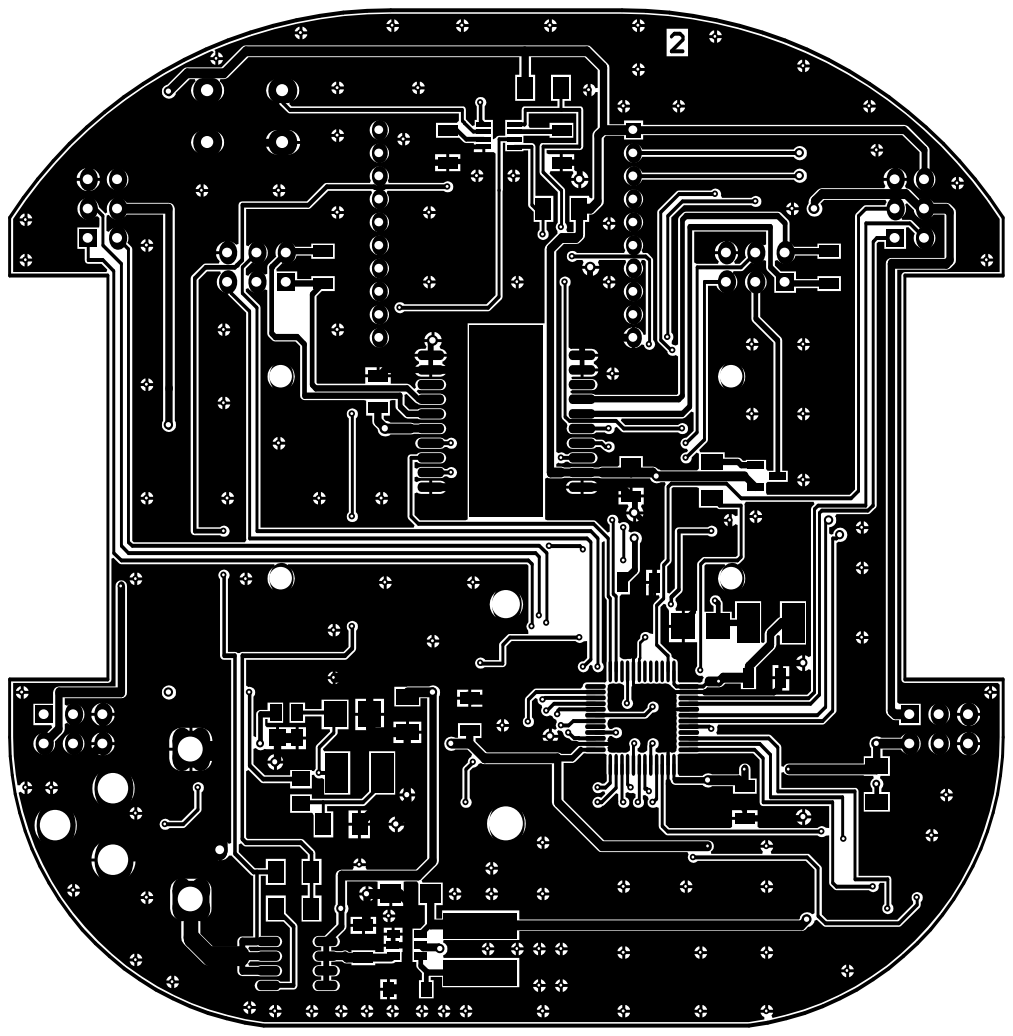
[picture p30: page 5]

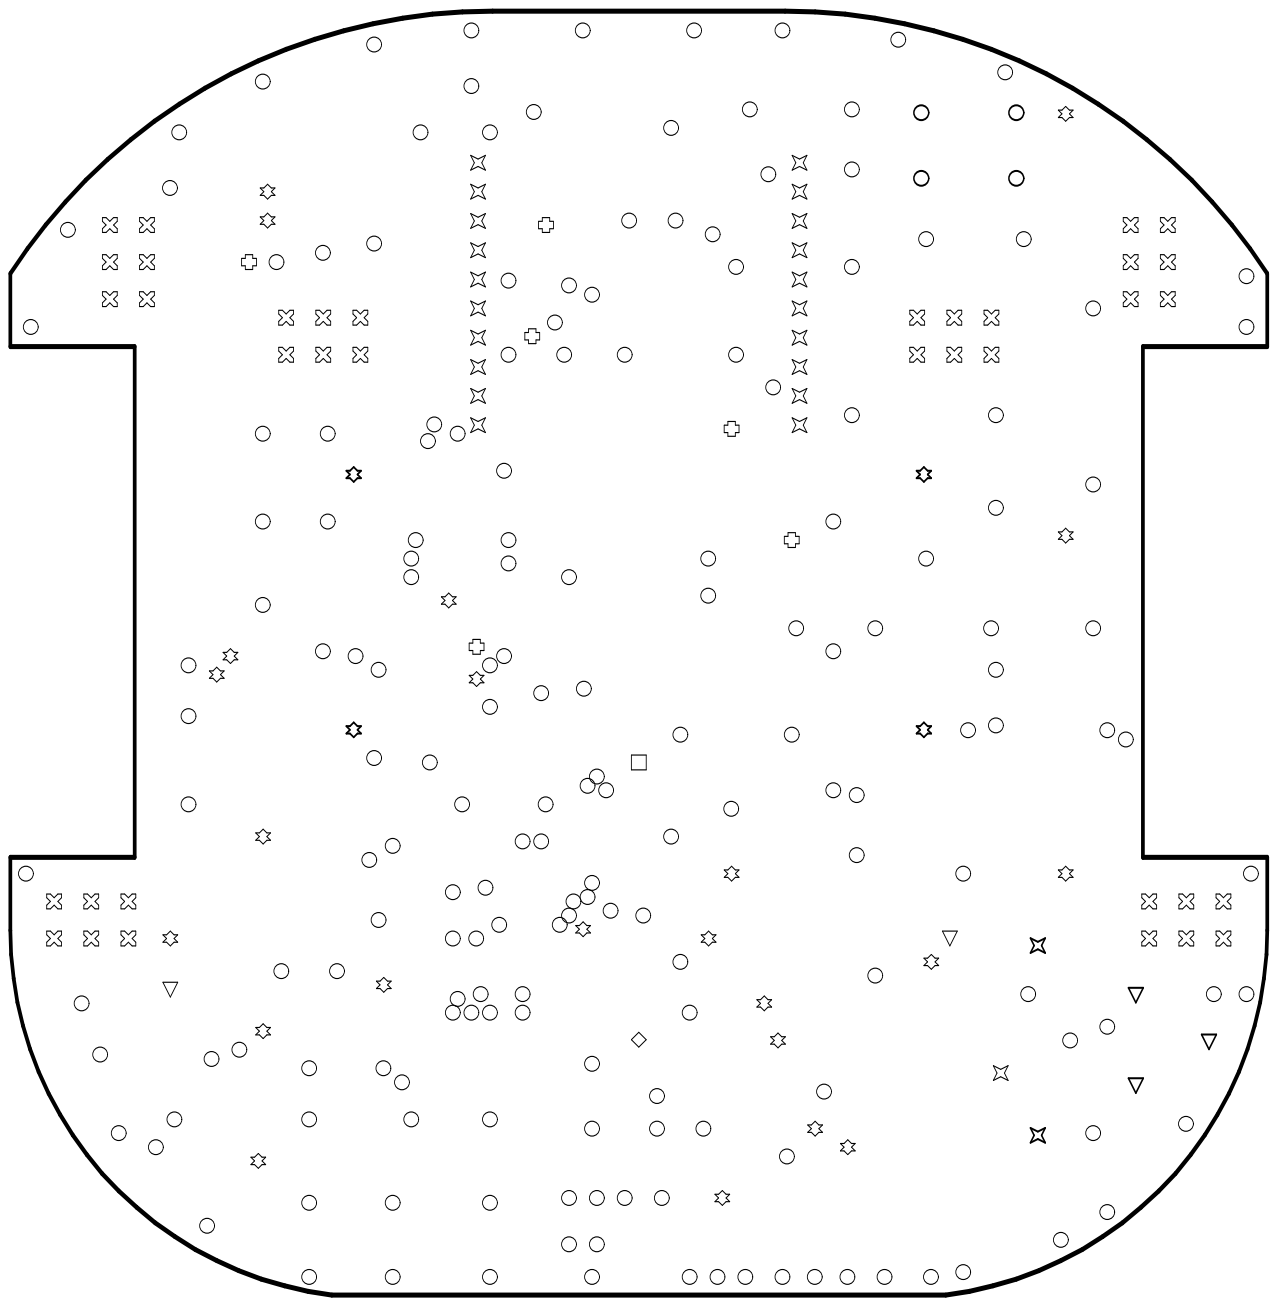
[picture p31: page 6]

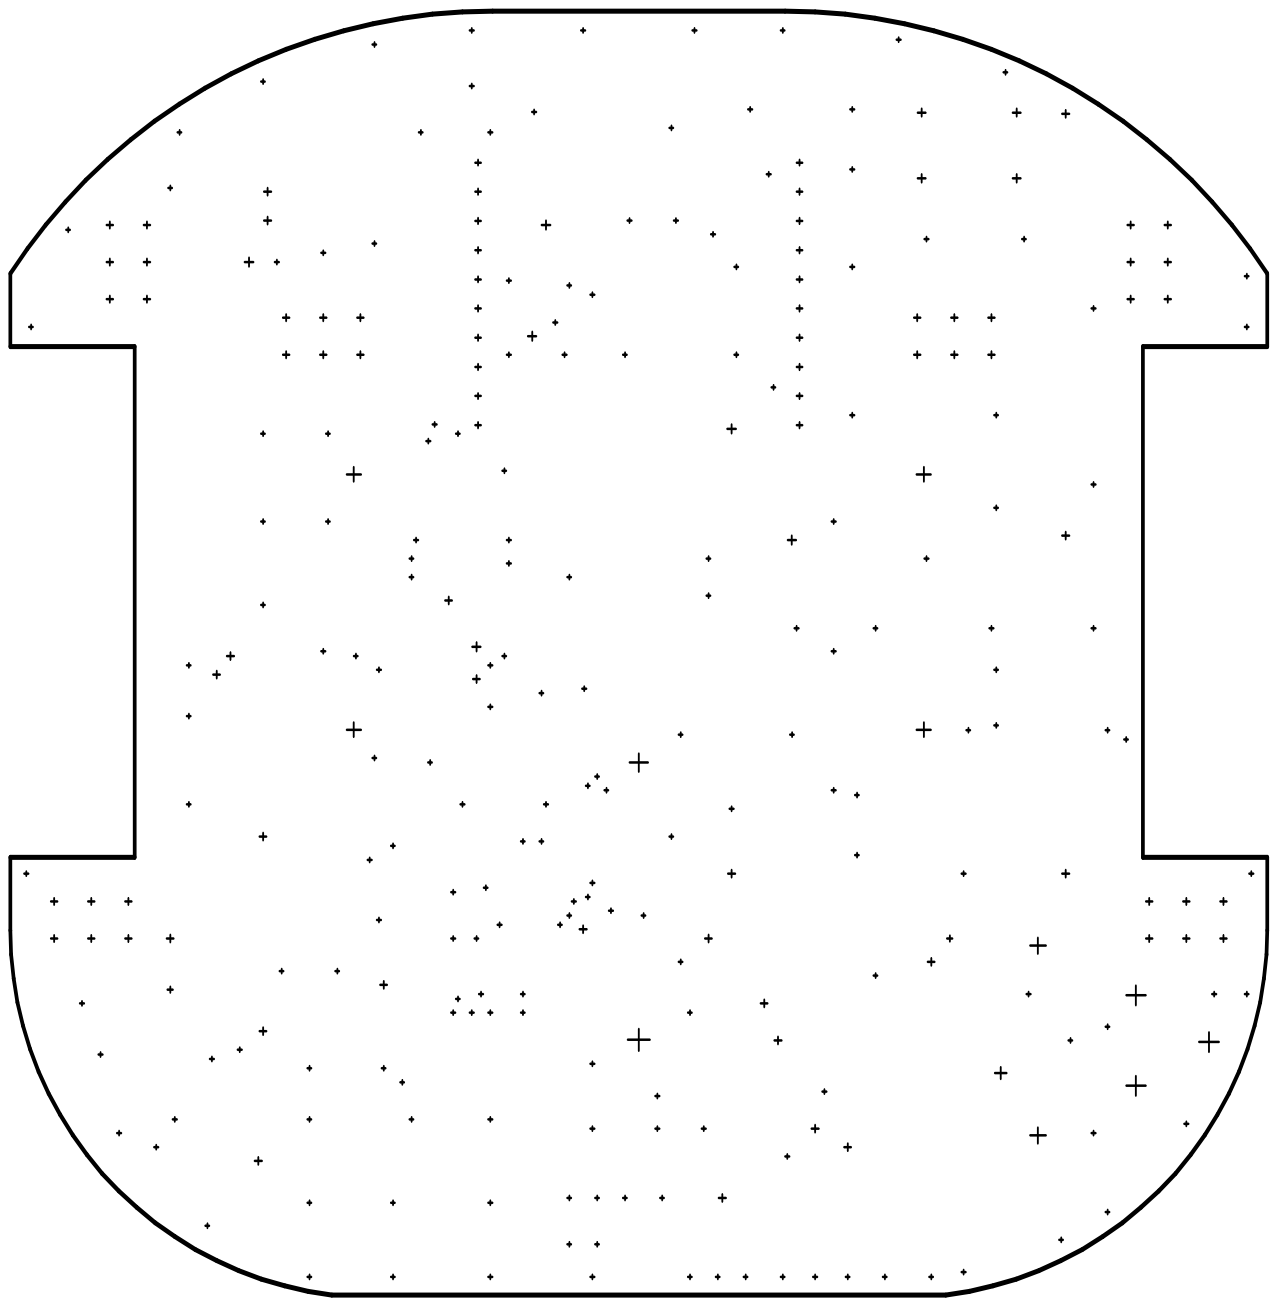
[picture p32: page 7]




Designator | Description | Quantity | Distributeur | Value

B21 | Keystone 1294 | 1 | Radiospares: 172-5845 / Farnell: 1650674

C101, C102, C103, C104, C301, C302, C303, C304 | CAP 100nF 50V ±10% 1206 (3216 Metric) Thickness 1.7mm SMD | 8 | | 100nF

C105, C207 | Solid Tantalum Chip Capacitor, Standard T491 Series - Industrial Grade | 2 | | 2.2µF

C201 | CAP 10µF 25V ±10% 1206 (3216 Metric) Thickness 1mm SMD | 1 | Farnell : 2497120 | 10µF

C202 | CAP Tantalum, Body B, 150µF / 6.3V | 1 | Farnell : 2491485 | 150uF

C205 | CAP 100nF 50V ±10% 1206 (3216 Metric) Thickness 1.7mm SMD | 1 | Farnell : 1856586 | 10nF

C206 | CAP 100nF 50V ±10% 1206 (3216 Metric) Thickness 1.7mm SMD | 1 | Farnell : 2497117 | 68nF

D101 | SMD Bi-Color Top LED, WL-SBTW, Red & Bright Green | 1 | Farnell : 2322113

D200 | TVS Diode WE-TVS-HS, VRWM=3.3V | 1

D204 | Schottky Power Rectifier, 2-Pin SOD-123, Pb-Free, Tape and Reel | 1 | Farnell : 1431045

J21 | Low Voltage Power Supply Connector | 1 | Farnell : 2472153

J101 | | 1 | Farnell : 1667729

K21 | SPST - MicroSwitch | 1 | Farnell: 2435161

L101, L202 | Inductor SMD | 2 | | 5.6µH
L201 | SMD Shielded Tiny Power Inductor WE-TPC, L = 22.0 µH | 1 | Farnell : 1635855

Moteur_Droit, Moteur_Gauche | | 2

P31 | Header, 3-Pin, Dual row | 1 | Farnell : 1022231

P32 | Header, 3-Pin, Dual row | 1 | Farnell : 1022231

P33, P34, P35, P36 | Header, 3-Pin, Dual row | 4 | Farnell : 1022231
Q22 | Single P-Channel Trench MOSFET, -20 V, -55 to 150 degC, 3-Pin SOT23, Tape and Reel | 1 | Farnell : 2498580

Q23 | P-Channel 30V (D-S) Rated MOSFET | 1

R101 | 1K8 0.125W 5% 0805 (2012 Metric) SMD | 1 | | 1.8K

R102 | 330R 0.125W 5% 0805 (2012 Metric) SMD | 1 | | 330 ohm

R104, R105, R106, R107, R201, R203, R301 | 10K 0.25W 5% 1206 (3216 Metric) SMD | 7 | | 10K

R108 | 10K 0.25W 5% 1206 (3216 Metric) SMD | 1 | | 0K

R204 | 10K 0.25W 5% 1206 (3216 Metric) SMD | 1 | | 10K

R205 | 10K 0.25W 5% 1206 (3216 Metric) SMD | 1 | | 100K

R206 | 10K 0.25W 5% 1206 (3216 Metric) SMD | 1 | | 10R

R213 | 270K 0.125W 5% 0805 (2012 Metric) SMD | 1 | | 270K

R214 | 10K 0.25W 5% 1206 (3216 Metric) SMD | 1 | | 100K

R216 | 10K 0.25W 5% 1206 (3216 Metric) SMD | 1 | | 1K

U11 | STM32 ARM-based 32-bit MCU with 32 Kbytes Flash, 48-pin LQFP, Industrial Temperature | 1 | Farnell : 1972391

U12 | Xbee RF transceiver from Digi | 1

U20 | Pushbutton On / Off Controller with µP Interrupt, 8-pin SOT23 (TS8-8), 0 to 70 degC, Pb-Free, Tape and Reel | 1

U21 | | 1 | Farnell : 2514159

U31 | Dual Full Bridge Driver | 1 | Radiospares : 880-5308

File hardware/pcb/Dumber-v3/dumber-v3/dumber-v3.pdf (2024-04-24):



is used Populate only
if TC1186 is used
þÿ1µF GND
BUTTON_SENSE CHARGER_ST2

2 ~{SHDN} 3 ~{ERROR}4 Vout 5 U6 TC1186 +BATT GND

1 ONT 2 PB 3 Vin 4 KILL 5 PDT 6 EN 7

INSA - GEI
Sheet: /Power_Charge/
File: power_charge.kicad_sch
Id: 2/3 Title: Power & Charge


1 GND 10 DIO4 11 ~{CTS}12 ~{SLEEP}13 ASSOCIATE 15 ~{RTS} 16 DIO3 17 DIO2 18 DIO1 19 DOUT 2 DIO0 20 DIN 3 DIO12 4 ~{RESET} 5 RSSI 6 DIO11 7 ~{DTR}/SLEEP_REQ 9 U1XBEE-3 C16

INSA - GEI
Sheet: /Cpu/
File: cpu.kicad_sch
Id: 3/3 Title: CPU + Com + Motors

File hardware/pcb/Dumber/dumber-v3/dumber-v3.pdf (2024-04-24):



4 ~{INT}5 ~{EN}6 PDT 7 ~{KILL}8 U3

File: power_charge.kicad_sch Sheet: /Power_Charge/
Id: 2/3 Title: Power & Charge


1 PA0 10 PA1 11 PA2 12 PA3 13 PA4 14 PA5 15 PA6 16 PA7 17 PB0 18 PB1 19 PC13 2 PB2 20 PB10 21 PB11 22 VSS 23 VDD 24 PB12 25 PB13 26 PB14 27 PB15 28 PA8 29 PC14 3 PA9 30 PA10 31 PA11 32 PA12 33 PA13 34 VSS 35 VDDIO2 36 PA14 37 PA15 38 PB3 39 PC15 4 PB4 40 PB5 41 PB6 42 PB7 43 BOOT0 44 PB8 45 PB9 46 VSS 47 VDD 48 PF0 5 PF1 6 NRST 7 VSSA

1 GND 10 DIO4 11 ~{CTS} 12 ~{SLEEP} 13 ASSOCIATE 15 ~{RTS} 16 DIO3 17 DIO2 18 DIO1 19 DOUT 2 DIO0 20 DIN 3 DIO12 4 ~{RESET} 5 RSSI 6 DIO11 7 ~{DTR}/SLEEP_REQ 9 U1XBEE-3 C12

File: cpu.kicad_sch Sheet: /Cpu/
Id: 3/3 Title: CPU + Com + Motors

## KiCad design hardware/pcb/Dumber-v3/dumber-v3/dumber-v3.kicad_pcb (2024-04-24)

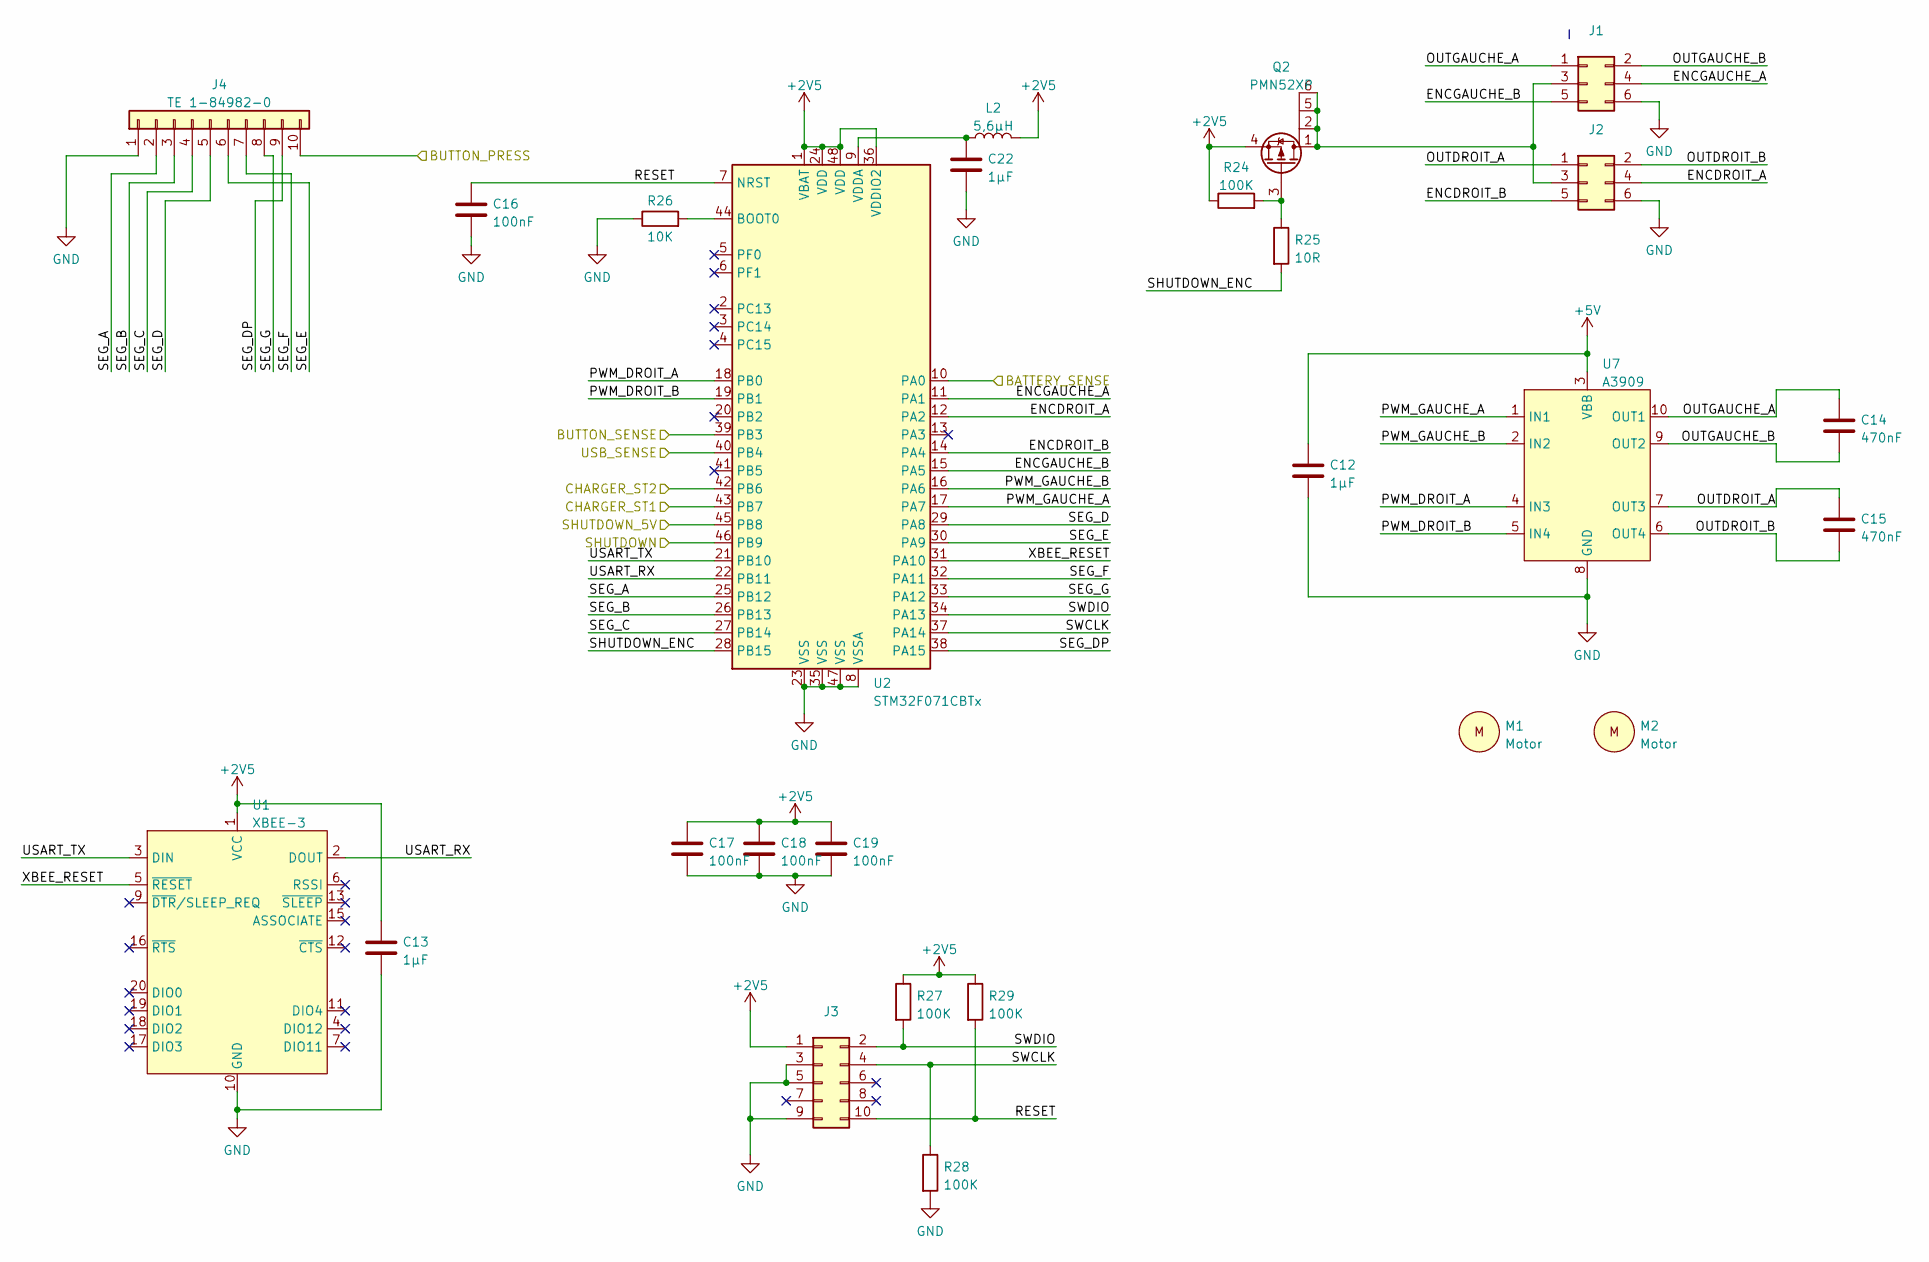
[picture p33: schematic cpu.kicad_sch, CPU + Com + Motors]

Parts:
C12, C13, C22: 1µF; C_0805_2012Metric
C14, C15: 470nF; C_0805_2012Metric
C16, C17, C18, C19: 100nF; C_0805_2012Metric
J1, J2: Conn_02x03_Odd_Even; IDC-Header_2x03_P2.54mm_Vertical
J3: Conn_02x05_Odd_Even; PinHeader_2x05_P1.27mm_Horizontal
J4: TE 1-84982-0
L2: 5,6µH; L_1812_4532Metric
M1, M2: Motor; Motor Pololu HPCB with encoder
Q2: PMN52XP; TSOP-6_1.65x3.05mm_P0.95mm
R24, R27, R28, R29: 100K; R_0805_2012Metric
R25: 10R; R_0805_2012Metric
R26: 10K; R_0805_2012Metric
U1: XBEE-3; XBEE-3-TH
U2: STM32F071CBTx; LQFP-48_7x7mm_P0.5mm
U7: A3909; SSOP-10_3.9x4.9mm_P1.00mm

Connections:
+2V5: C13.1, C17.1, C18.1, C19.1, J3.1, L2.2, Q2.4 (S), R24.1, R27.1, R29.1, U1.1 (VCC), U2.1 (VBAT), U2.24 (VDD), U2.36 (VDDIO2), U2.48 (VDD); also elsewhere on the board
+5V: C12.1, U7.3 (VBB); also elsewhere on the board
/Cpu/BATTERY_SENSE: U2.10 (PA0); also elsewhere on the board
/Cpu/BUTTON_PRESS: J4.10; also elsewhere on the board
/Cpu/BUTTON_SENSE: U2.39 (PB3); also elsewhere on the board
/Cpu/CHARGER_ST1: U2.43 (PB7); also elsewhere on the board
/Cpu/CHARGER_ST2: U2.42 (PB6); also elsewhere on the board
/Cpu/ENCDROIT_A: J2.4, U2.12 (PA2)
/Cpu/ENCDROIT_B: J2.5, U2.14 (PA4)
/Cpu/ENCGAUCHE_A: J1.4, U2.11 (PA1)
/Cpu/ENCGAUCHE_B: J1.5, U2.15 (PA5)
/Cpu/OUTDROIT_A: C15.1, J2.1, U7.7 (OUT3)
/Cpu/OUTDROIT_B: C15.2, J2.2, U7.6 (OUT4)
/Cpu/OUTGAUCHE_A: C14.1, J1.1, U7.10 (OUT1)
/Cpu/OUTGAUCHE_B: C14.2, J1.2, U7.9 (OUT2)
/Cpu/PWM_DROIT_A: U2.18 (PB0), U7.4 (IN3)
/Cpu/PWM_DROIT_B: U2.19 (PB1), U7.5 (IN4)
/Cpu/PWM_GAUCHE_A: U2.17 (PA7), U7.1 (IN1)
/Cpu/PWM_GAUCHE_B: U2.16 (PA6), U7.2 (IN2)
/Cpu/RESET: C16.1, J3.10, R29.2, U2.7 (NRST)
/Cpu/SEG_A: J4.2, U2.25 (PB12)
/Cpu/SEG_B: J4.3, U2.26 (PB13)
/Cpu/SEG_C: J4.4, U2.27 (PB14)
/Cpu/SEG_D: J4.5, U2.29 (PA8)
/Cpu/SEG_DP: J4.9, U2.38 (PA15)
/Cpu/SEG_E: J4.6, U2.30 (PA9)
/Cpu/SEG_F: J4.7, U2.32 (PA11)
/Cpu/SEG_G: J4.8, U2.33 (PA12)
/Cpu/SHUTDOWN: U2.46 (PB9); also elsewhere on the board
/Cpu/SHUTDOWN_5V: U2.45 (PB8); also elsewhere on the board
/Cpu/SHUTDOWN_ENC: R25.2, U2.28 (PB15)
/Cpu/SWCLK: J3.4, R28.1, U2.37 (PA14)
/Cpu/SWDIO: J3.2, R27.2, U2.34 (PA13)
/Cpu/USART_RX: U1.2 (DOUT), U2.22 (PB11)
/Cpu/USART_TX: U1.3 (DIN), U2.21 (PB10)
/Cpu/USB_SENSE: U2.40 (PB4); also elsewhere on the board
/Cpu/XBEE_RESET: U1.5 (~RESET), U2.31 (PA10)
GND: C12.2, C13.2, C16.2, C17.2, C18.2, C19.2, C22.2, J1.6, J2.6, J3.3, J3.5, J3.9, J4.1, R26.1, R28.2, U1.10 (GND), U2.8 (VSSA), U2.23 (VSS), U2.35 (VSS), U2.47 (VSS), U7.8 (GND); also elsewhere on the board
unnamed: J1.3, J2.3, Q2.1 (D), Q2.2 (D), Q2.5 (D), Q2.6 (D)
unnamed: Q2.3 (G), R24.2, R25.1
unnamed: R26.2, U2.44 (BOOT0)
unnamed: C22.1, L2.1, U2.9 (VDDA)

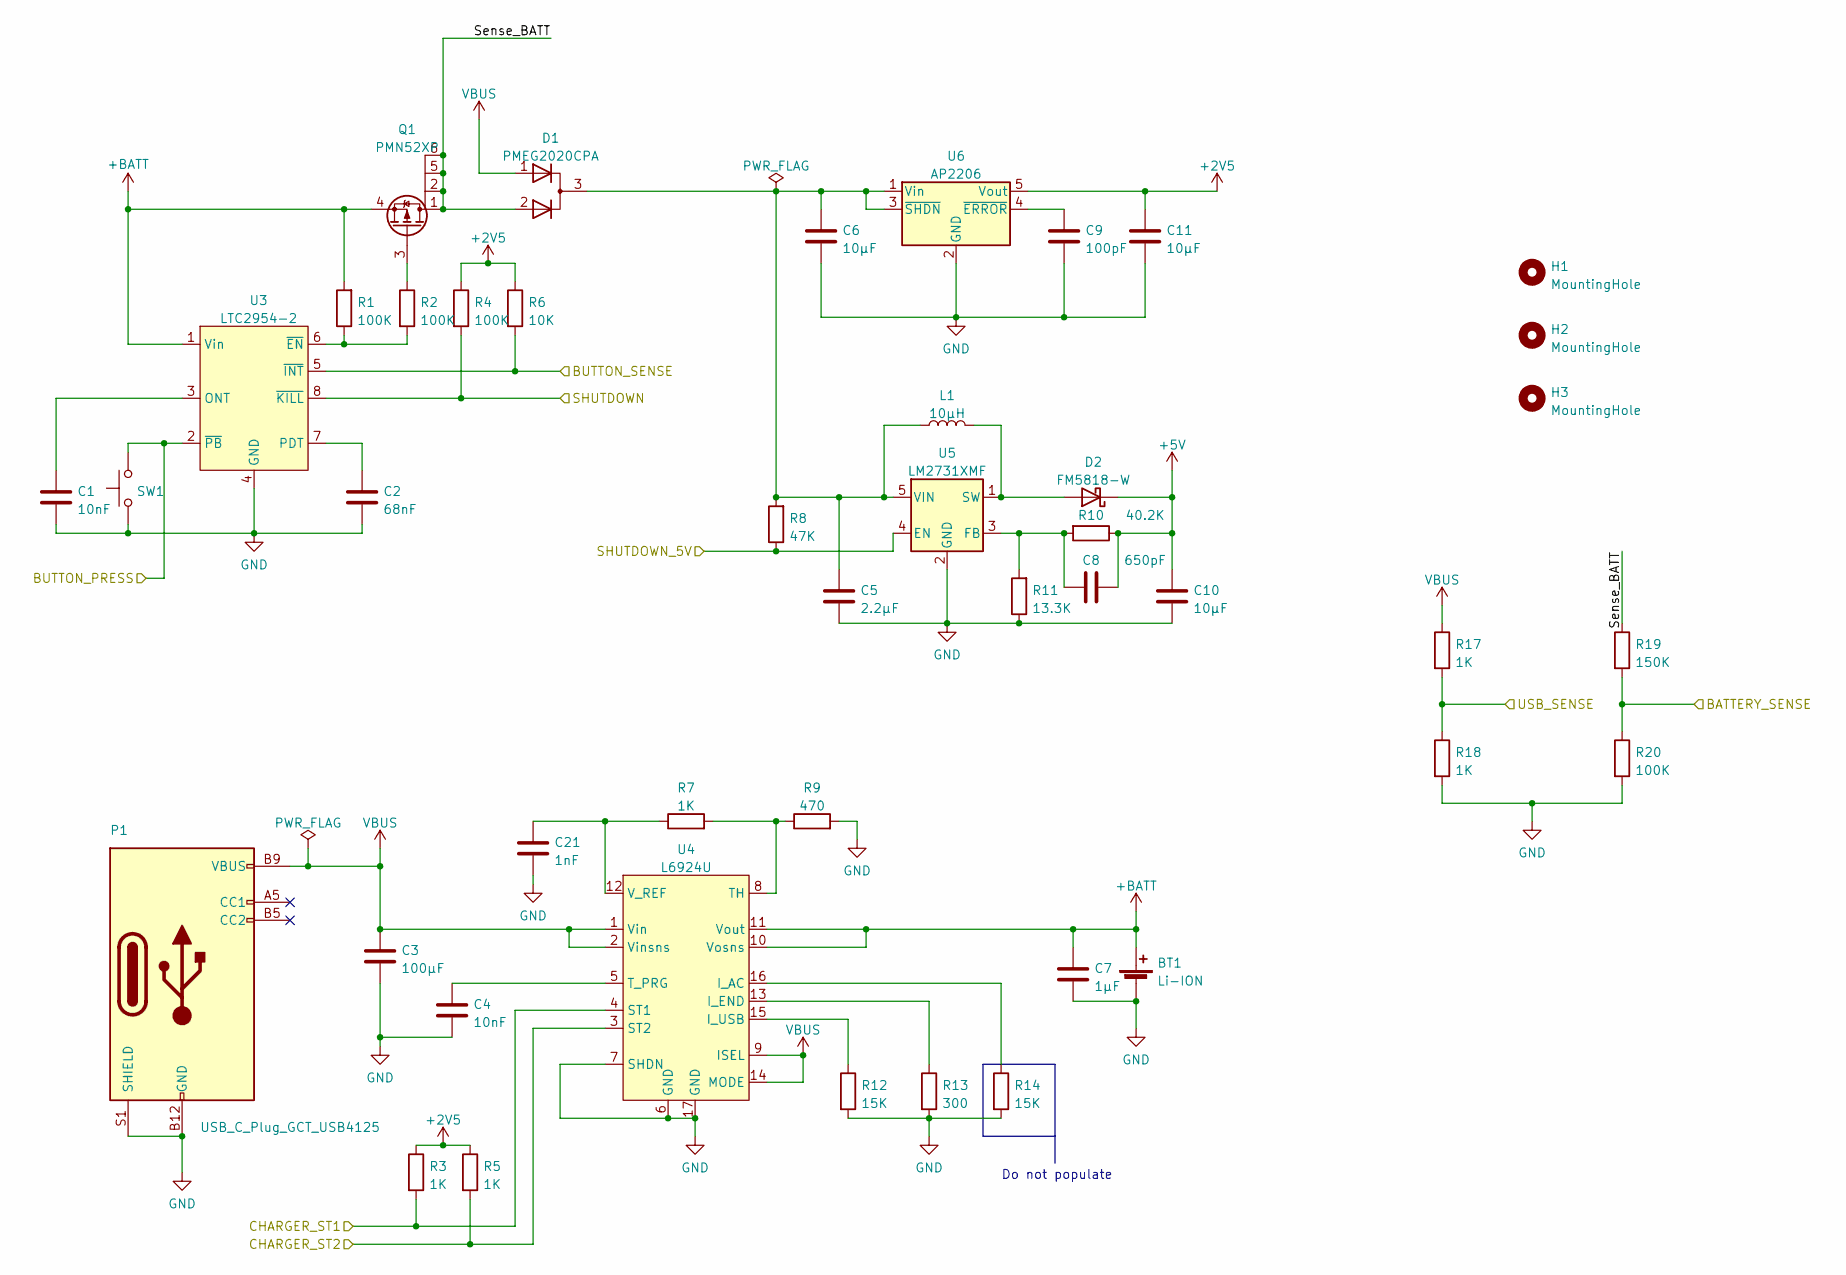
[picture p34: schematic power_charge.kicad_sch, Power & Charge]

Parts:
BT1: Li-ION; Battery-14500
C1, C4: 10nF; C_0805_2012Metric
C2: 68nF; C_0805_2012Metric
C3: 100µF; C_1210_3225Metric
C5: 2.2µF; C_0805_2012Metric
C6, C11: 10µF; C_0805_2012Metric
C7: 1µF; C_0805_2012Metric
C8: 650pF; C_0805_2012Metric
C9: 100pF; C_0805_2012Metric
C10: 10µF; C_1210_3225Metric
C21: 1nF; C_0805_2012Metric
D1: PMEG2020CPA; Nexperia_SOT-1061
D2: FM5818-W; D_SMA
H1, H2, H3: MountingHole; MountingHole_3.2mm_M3_ISO14580
L1: 10µH; L_Bourns_SRP7028A_7.3x6.6mm
P1: USB_C_Plug_GCT_USB4125; USB_C_Receptacle_GCT_USB4125
Q1: PMN52XP; TSOP-6_1.65x3.05mm_P0.95mm
R1, R2, R4, R20: 100K; R_0805_2012Metric
R3, R5, R7, R17, R18: 1K; R_0805_2012Metric
R6: 10K; R_0805_2012Metric
R8: 47K; R_0805_2012Metric
R9: 470; R_0805_2012Metric
R10: 40.2K; R_0805_2012Metric
R11: 13.3K; R_0805_2012Metric
R12, R14: 15K; R_0805_2012Metric
R13: 300; R_0805_2012Metric
R19: 150K; R_0805_2012Metric
SW1: SW_Push; Panasonic_EVQPUJ_EVQPUA
U3: LTC2954-2; SOT-23-8
U4: L6924U; L6924UTR
U5: LM2731XMF; SOT-23-5
U6: AP2206; SOT-23-5

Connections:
+2V5: C11.1, R3.1, R4.1, R5.1, R6.1, U6.5 (Vout); also elsewhere on the board
+5V: C8.2, C10.1, D2.1 (K), R10.1; also elsewhere on the board
+BATT: BT1.1 (+), C7.1, Q1.4 (S), R1.2, U3.1 (Vin), U4.10 (Vosns), U4.11 (Vout)
/Cpu/BATTERY_SENSE: R19.2, R20.1; also elsewhere on the board
/Cpu/BUTTON_PRESS: SW1.2, U3.2 (~PB); also elsewhere on the board
/Cpu/BUTTON_SENSE: R6.2, U3.5 (~INT); also elsewhere on the board
/Cpu/CHARGER_ST1: R3.2, U4.4 (ST1); also elsewhere on the board
/Cpu/CHARGER_ST2: R5.2, U4.3 (ST2); also elsewhere on the board
/Cpu/SHUTDOWN: R4.2, U3.8 (~KILL); also elsewhere on the board
/Cpu/SHUTDOWN_5V: R8.1, U5.4 (EN); also elsewhere on the board
/Cpu/USB_SENSE: R17.2, R18.1; also elsewhere on the board
/Power_Charge/Sense_BATT: D1.2 (K), Q1.1 (D), Q1.2 (D), Q1.5 (D), Q1.6 (D), R19.1
GND: BT1.2 (-), C1.2, C2.2, C3.2, C4.2, C5.2, C6.2, C7.2, C9.2, C10.2, C11.2, C21.2, P1.A12 (GND), P1.B12 (GND), P1.S1 (SHIELD), R9.2, R11.1, R12.2, R13.2, R14.2, R18.2, R20.2, SW1.1, U3.4 (GND), U4.6 (GND), U4.7 (SHDN), U4.17 (GND), U5.2 (GND), U6.2 (GND); also elsewhere on the board
unnamed: C1.1, U3.3 (ONT)
unnamed: C2.1, U3.7 (PDT)
unnamed: C4.1, U4.5 (T_PRG)
unnamed: C5.1, C6.1, D1.3 (A), L1.1, R8.2, U5.5 (VIN), U6.1 (Vin), U6.3 (~SHDN)
unnamed: C8.1, R10.2, R11.2, U5.3 (FB)
unnamed: C9.1, U6.4 (~ERROR)
unnamed: C21.1, R7.1, U4.12 (V_REF)
unnamed: D2.2 (A), L1.2, U5.1 (SW)
unnamed: Q1.3 (G), R2.1
unnamed: R1.1, R2.2, U3.6 (~EN)
unnamed: R7.2, R9.1, U4.8 (TH)
unnamed: R12.1, U4.15 (I_USB)
unnamed: R13.1, U4.13 (I_END)
unnamed: R14.1, U4.16 (I_AC)
VBUS: C3.1, D1.1 (K), P1.A9 (VBUS), P1.B9 (VBUS), R17.1, U4.1 (Vin), U4.2 (Vinsns), U4.9 (ISEL), U4.14 (MODE)

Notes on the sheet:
Do not populate

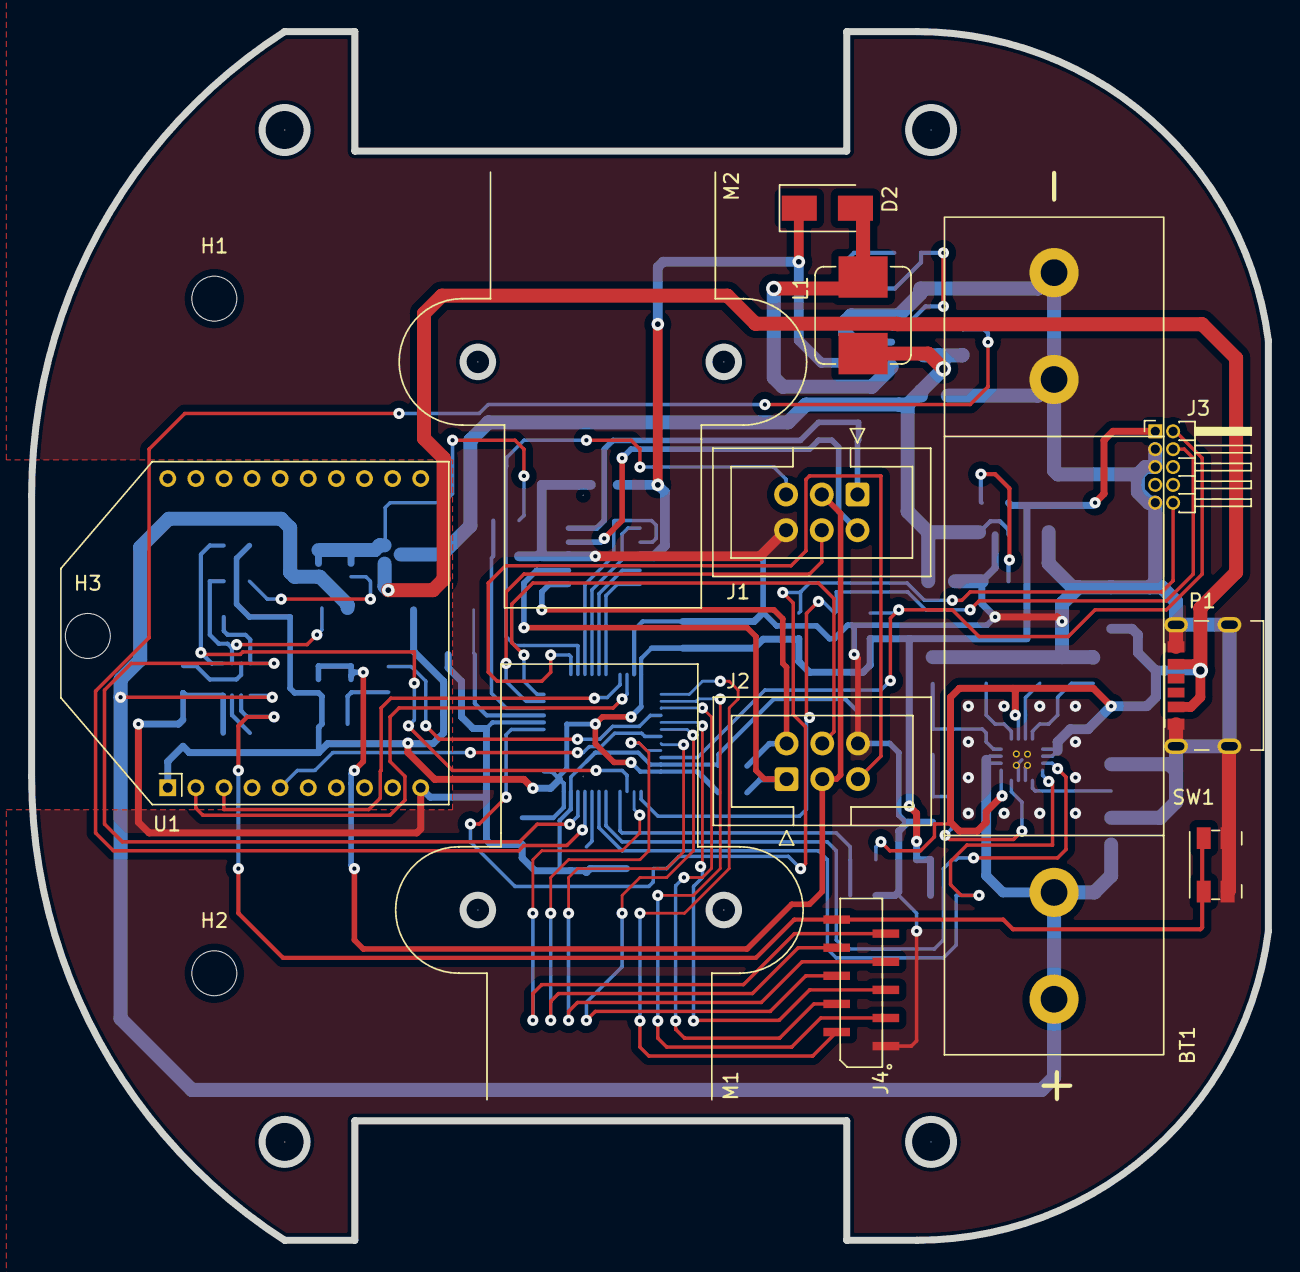
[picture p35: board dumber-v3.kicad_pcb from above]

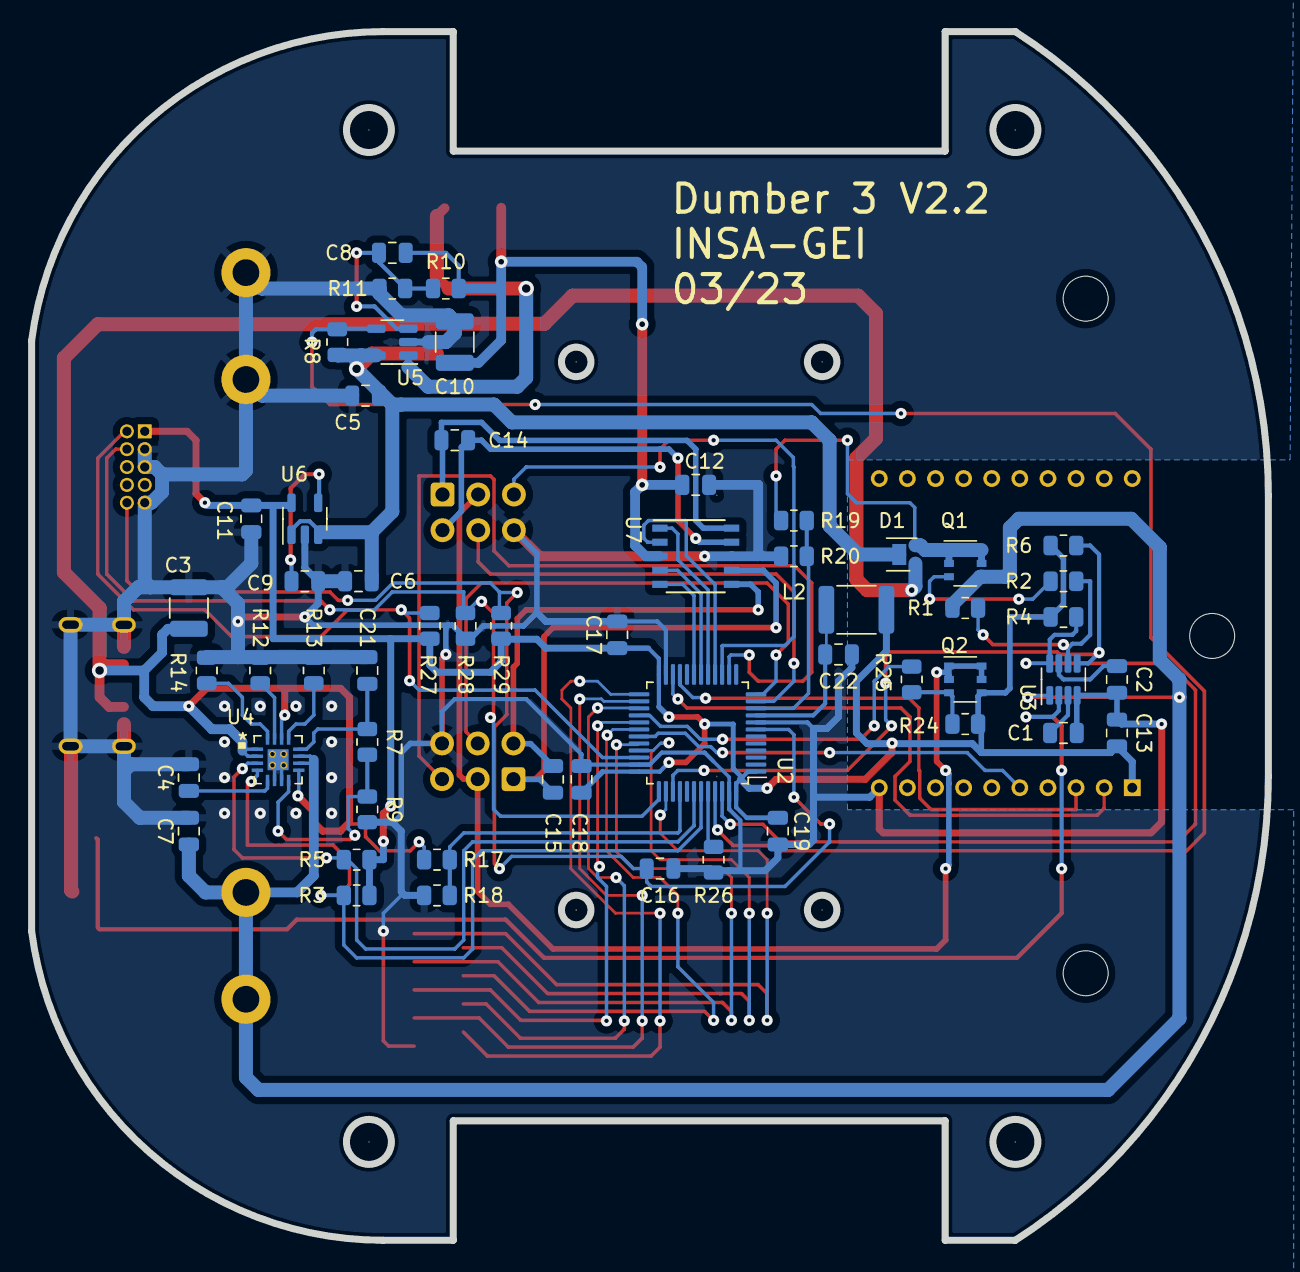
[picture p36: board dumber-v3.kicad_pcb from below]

Board: 2 copper layers, 88.0 x 86.0 mm, 70 parts (55 on the bottom side), 59 nets.

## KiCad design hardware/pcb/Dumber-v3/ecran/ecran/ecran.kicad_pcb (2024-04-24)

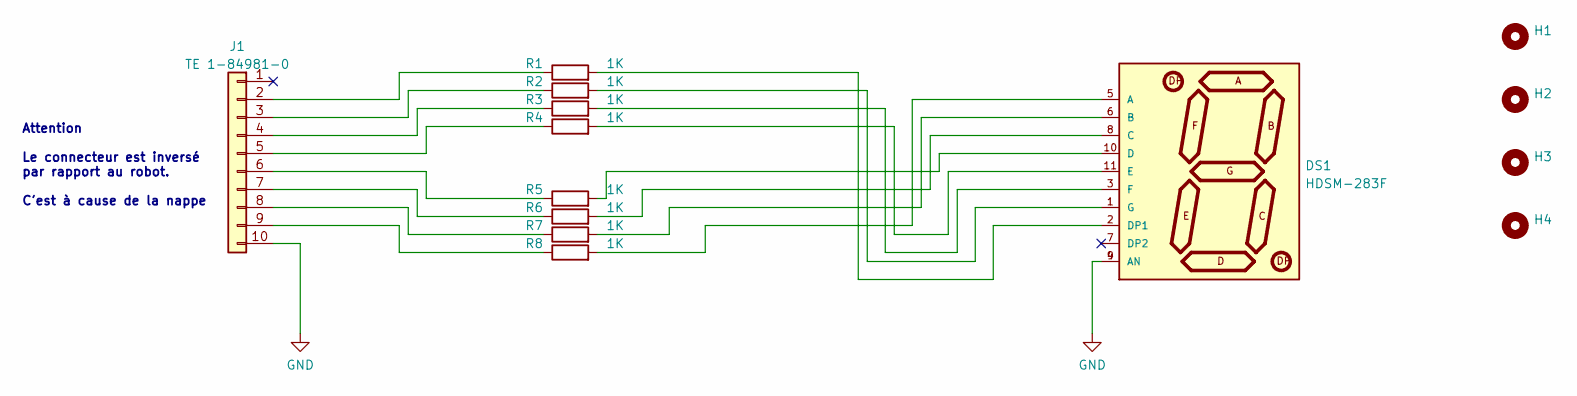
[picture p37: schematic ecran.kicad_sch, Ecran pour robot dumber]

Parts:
DS1: HDSM-283F; LED_HDSM-283F
H1, H2, H3, H4: MountingHole; MountingHole_3mm
J1: TE 1-84981-0
R1, R2, R3, R4, R5, R6, R7, R8: 1K; R_0805_2012Metric

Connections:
GND: DS1.4 (AN), DS1.9 (AN), J1.10
unnamed: DS1.1 (G), R2.2
unnamed: DS1.2 (DP1), R1.2
unnamed: DS1.3 (F), R3.2
unnamed: DS1.5 (A), R8.2
unnamed: DS1.6 (B), R7.2
unnamed: DS1.8 (C), R6.2
unnamed: DS1.10 (D), R5.2
unnamed: DS1.11 (E), R4.2
unnamed: J1.2, R1.1
unnamed: J1.3, R2.1
unnamed: J1.4, R3.1
unnamed: J1.5, R4.1
unnamed: J1.6, R5.1
unnamed: J1.7, R6.1
unnamed: J1.8, R7.1
unnamed: J1.9, R8.1

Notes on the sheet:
Attention Le connecteur est inversé par rapport au robot. C'est à cause de la nappe

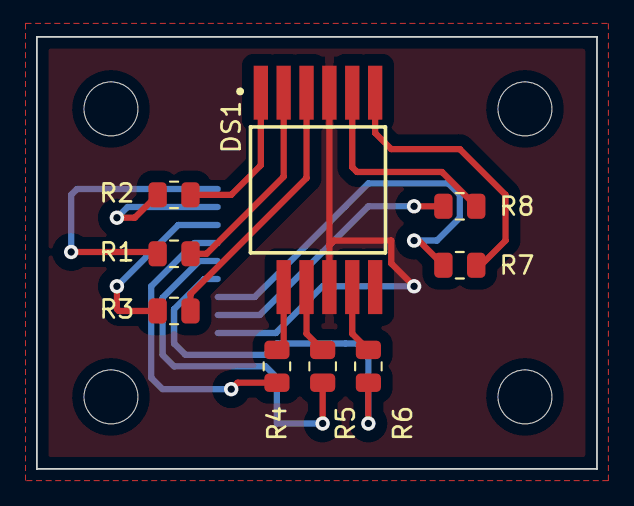
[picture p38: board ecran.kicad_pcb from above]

Board: 2 copper layers, 31.1 x 24.0 mm, 14 parts (1 on the bottom side), 17 nets.

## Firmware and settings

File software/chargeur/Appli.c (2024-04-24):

#include "stm32f10x.h"                  // Device header
#include <stdio.h>

volatile int32_t ITM_RxBuffer;

void SetLedOn(void);
void SetLedOff(void);
void RCC_Configuration(void);
void GetCurrentAndVoltage(uint32_t *current, uint32_t *voltage);
char VerifyVbatFastCharge(uint32_t voltage);

#define ADC1_DR_Address    ((uint32_t)0x4001244C)
#define STATE_IDLE 					0x0
#define STATE_FASTCHARGE 		0x01
#define STATE_SLOWCHARGE 		0x02
#define STATE_CHARGEFINISH 	0x03
#define STATE_CALIBRATION   0x10
#define STATE_OFF						0xFF

#define MIN_RATIO 					0
#define MAX_RATIO 					400

#define CURRENT_FASTCHARGE 		0x0C0
#define CURRENT_CHARGEFINISH 	0x00C

#define VERSION "01A"

/* Remarque: Pont diviseur sur 1.5 V pour 9V batterie*/

#define VOLTAGE_IDLE 					0x450  //  5V
#define VOLTAGE_FASTCHARGE 		0x960  //  1.8*6 =>10.80
#define VOLTAGE_ABSOLUTEMAX 	0xA10  //  12V

#define TEMPO_CHARGE_MAX				450*60   /* 45 minutes */		
#define TEMPO_CHARGEFINISH_MAX  12     /* 1.2 seconds */

#define SAFETY_MAX 6

struct MESURE
{
	uint16_t Current;
	uint16_t Voltage;
};

__IO struct MESURE ADCConvertedValue[1024];
 
uint32_t state= STATE_IDLE;
__IO uint8_t tick=0;
uint32_t mesure_vbat;
uint32_t mesure_courant;
uint32_t mincurrent;
uint32_t delta_counter=0;
uint32_t ratio_pwm=0;

uint32_t tempo_chargefinish=0;
uint32_t tempo_charge=0;

uint8_t start=0;
uint8_t cause_exit=0;
uint8_t safety_counter=0;

uint32_t initial_vbat;

uint32_t volatile min_vbat, max_vbat;

void delay(uint32_t time)
{
volatile uint32_t counter = time;
	
	while (counter!=0)
	{
		__nop();
		counter--;
	}
}

/**
  * @brief  Main function, that compute charge algorithms.
  * @param  None
  * @retval None
  */
int main (void)
{
GPIO_InitTypeDef GPIO_InitStructure;
ADC_InitTypeDef ADC_InitStructure;
DMA_InitTypeDef DMA_InitStructure;
TIM_TimeBaseInitTypeDef  TIM_TimeBaseStructure;
TIM_OCInitTypeDef  TIM_OCInitStructure;

char count=0;
	
	SysTick_Config(7200000);
	RCC_Configuration();
	
	/* PA8 -> Alternate function (TIM1_CH1) */
	GPIO_InitStructure.GPIO_Mode = GPIO_Mode_AF_PP;
	GPIO_InitStructure.GPIO_Speed = GPIO_Speed_50MHz;
	GPIO_InitStructure.GPIO_Pin = GPIO_Pin_8;
	GPIO_Init(GPIOA, &GPIO_InitStructure);
	
	/* PA1 -> Analog input (ADC1_CH1) -> V_Batterie
	   PA2 -> Analog input (ADC1_CH2) -> V_Courant
	*/
	GPIO_InitStructure.GPIO_Mode = GPIO_Mode_AIN;
	GPIO_InitStructure.GPIO_Pin = GPIO_Pin_1 | GPIO_Pin_2;
	GPIO_Init(GPIOA, &GPIO_InitStructure);
	
	/* PB12 -> Output Push Pull (Act Led) */
	GPIO_InitStructure.GPIO_Mode = GPIO_Mode_Out_PP;
	GPIO_InitStructure.GPIO_Speed = GPIO_Speed_50MHz;
	GPIO_InitStructure.GPIO_Pin = GPIO_Pin_12;
	GPIO_Init(GPIOB, &GPIO_InitStructure);
	
	/* ADC_IN1 = PA1 = Mesure_VBAT 
	   ADC_IN2 = PA2 = Mesure_Courant 
	*/
/* DMA1 channel1 configuration ----------------------------------------------*/
  DMA_DeInit(DMA1_Channel1);
  DMA_InitStructure.DMA_PeripheralBaseAddr = ADC1_DR_Address;
  DMA_InitStructure.DMA_MemoryBaseAddr = (uint32_t)&ADCConvertedValue;
  DMA_InitStructure.DMA_DIR = DMA_DIR_PeripheralSRC;
  DMA_InitStructure.DMA_BufferSize = 2*1024;
  DMA_InitStructure.DMA_PeripheralInc = DMA_PeripheralInc_Disable;
  DMA_InitStructure.DMA_MemoryInc = DMA_MemoryInc_Enable;
  DMA_InitStructure.DMA_PeripheralDataSize = DMA_PeripheralDataSize_HalfWord;
  DMA_InitStructure.DMA_MemoryDataSize = DMA_MemoryDataSize_HalfWord;
  DMA_InitStructure.DMA_Mode = DMA_Mode_Circular;
  DMA_InitStructure.DMA_Priority = DMA_Priority_High;
  DMA_InitStructure.DMA_M2M = DMA_M2M_Disable;
  DMA_Init(DMA1_Channel1, &DMA_InitStructure);
  
  /* Enable DMA1 channel1 */
  DMA_Cmd(DMA1_Channel1, ENABLE);
  
  /* ADC1 configuration ------------------------------------------------------*/
  ADC_InitStructure.ADC_Mode = ADC_Mode_Independent;
  ADC_InitStructure.ADC_ScanConvMode = ENABLE;
  ADC_InitStructure.ADC_ContinuousConvMode = ENABLE;
  ADC_InitStructure.ADC_ExternalTrigConv = ADC_ExternalTrigConv_None;
  ADC_InitStructure.ADC_DataAlign = ADC_DataAlign_Right;
  ADC_InitStructure.ADC_NbrOfChannel = 2;
  ADC_Init(ADC1, &ADC_InitStructure);

  /* ADC1 regular channel14 configuration */ 
  ADC_RegularChannelConfig(ADC1, ADC_Channel_2, 1, ADC_SampleTime_55Cycles5);
  ADC_RegularChannelConfig(ADC1, ADC_Channel_1, 2, ADC_SampleTime_55Cycles5);

  /* Enable ADC1 DMA */
  ADC_DMACmd(ADC1, ENABLE);
  
  /* Enable ADC1 */
  ADC_Cmd(ADC1, ENABLE);

  /* Enable ADC1 reset calibration register */   
  ADC_ResetCalibration(ADC1);
  /* Check the end of ADC1 reset calibration register */
  while(ADC_GetResetCalibrationStatus(ADC1));

  /* Start ADC1 calibration */
  ADC_StartCalibration(ADC1);
  /* Check the end of ADC1 calibration */
  while(ADC_GetCalibrationStatus(ADC1));
     
  /* Start ADC1 Software Conversion */ 
  ADC_SoftwareStartConvCmd(ADC1, ENABLE);	
	
	/* TIM1_CH1+CH2 = PA8+PA9 = CMD_MOS */
  /* Time base configuration */
  TIM_TimeBaseStructure.TIM_Period = 512;
  TIM_TimeBaseStructure.TIM_Prescaler = 0;
  TIM_TimeBaseStructure.TIM_ClockDivision = 0;
  TIM_TimeBaseStructure.TIM_CounterMode = TIM_CounterMode_Up;

  TIM_TimeBaseInit(TIM1, &TIM_TimeBaseStructure);

  /* PWM2 Mode configuration: Channel1 */
  TIM_OCInitStructure.TIM_OCMode = TIM_OCMode_PWM2;
  TIM_OCInitStructure.TIM_OutputState = TIM_OutputState_Disable;
  TIM_OCInitStructure.TIM_Pulse = ratio_pwm;
  TIM_OCInitStructure.TIM_OCPolarity = TIM_OCPolarity_Low;

  TIM_OC1Init(TIM1, &TIM_OCInitStructure);
  TIM_OC2Init(TIM1, &TIM_OCInitStructure);
	
  TIM_OC1PreloadConfig(TIM1, TIM_OCPreload_Enable);
  TIM_OC2PreloadConfig(TIM1, TIM_OCPreload_Enable);
	
  TIM_ARRPreloadConfig(TIM1, ENABLE);

  /* TIM1 enable counter */
  TIM_Cmd(TIM1, ENABLE);	
	
	printf ("Let's start ...\n\r");
	
	/* Wait x ms, in order for adc and DMA to acquire some data */
	delay(1000000); // ~ 200 ms
	GetCurrentAndVoltage(&mesure_courant, &initial_vbat);
	
	min_vbat = (uint32_t)(initial_vbat*0.95);
	max_vbat = (uint32_t)(initial_vbat*1.05);
	
	while (1)
	{
		if (tick == 1)
		{
			tick=0;
			count++;
			GetCurrentAndVoltage(&mesure_courant, &mesure_vbat);
			
			VerifyVbatFastCharge(mesure_vbat);
			
			switch (state)
			{
				case STATE_IDLE:

				  if (mesure_vbat >= max_vbat) state = STATE_FASTCHARGE;
				  if (mesure_vbat <= min_vbat) state = STATE_FASTCHARGE;
				  if (mesure_courant !=0) state = STATE_FASTCHARGE;
				
				  tempo_chargefinish=0;
					tempo_charge=0;
				  ratio_pwm = MIN_RATIO;
				  safety_counter=0;
				  mincurrent=0xFFFF;
				  delta_counter=0;
					break;
				
				case STATE_FASTCHARGE:
				
					tempo_charge++;
				 
				  if (mesure_vbat >= VOLTAGE_ABSOLUTEMAX) safety_counter++;
					else safety_counter=0;
							
				  if ((safety_counter >= SAFETY_MAX) || (tempo_charge >= TEMPO_CHARGE_MAX))
					{
						ratio_pwm= MIN_RATIO;
						TIM_SetCompare1(TIM1, (uint16_t)ratio_pwm);
						state = STATE_CHARGEFINISH;
					}
					else
					{
						if (VerifyVbatFastCharge(mesure_vbat) !=0)
						{
							state = STATE_SLOWCHARGE;
						}
						else
						{
							if (mesure_courant>= CURRENT_FASTCHARGE)
							{
								if (ratio_pwm > MIN_RATIO) ratio_pwm--;
							}
							else
							{
								if (ratio_pwm< MAX_RATIO) ratio_pwm ++;
							}
						}
					}
					break;
				
				case STATE_SLOWCHARGE:
					tempo_charge++;
				
				  if (mesure_vbat >= VOLTAGE_ABSOLUTEMAX) safety_counter++;
					else safety_counter=0;
				  
				  if (mesure_courant == 0) 
					{
						state = STATE_CHARGEFINISH;
						ratio_pwm= MIN_RATIO;
						TIM_SetCompare1(TIM1, (uint16_t)ratio_pwm);
					}
					
					if ((safety_counter >= SAFETY_MAX) || (tempo_charge >= TEMPO_CHARGE_MAX))
					{
						state = STATE_CHARGEFINISH;
						ratio_pwm= MIN_RATIO;
						TIM_SetCompare1(TIM1, (uint16_t)ratio_pwm);
						
						if (mesure_vbat >= VOLTAGE_ABSOLUTEMAX) cause_exit=1;
						else cause_exit=2;
					}
					else
					{
						if (mesure_courant<mincurrent) mincurrent=mesure_courant;
						
						/* detection du delta */
						if (mesure_courant>((uint32_t)((float)mincurrent*0.15))+mincurrent)
						{
							delta_counter++;
							
							if (delta_counter ==25)
							{
								ratio_pwm= MIN_RATIO;
								TIM_SetCompare1(TIM1, (uint16_t)ratio_pwm);
							
								state = STATE_CHARGEFINISH;						
								cause_exit=3;
							}
						}
						else delta_counter=0;
						
						if (mesure_vbat >= VOLTAGE_FASTCHARGE)
						{
							if (ratio_pwm > MIN_RATIO) ratio_pwm--;
						}
						else
						{
							if (ratio_pwm< MAX_RATIO) ratio_pwm ++;
						}
						
						if (mesure_courant>= CURRENT_FASTCHARGE)
						{
							if (ratio_pwm > MIN_RATIO) ratio_pwm--;
						}
						
						if ((mesure_courant<= CURRENT_CHARGEFINISH) && (mesure_courant>=2))
						{
							ratio_pwm=MIN_RATIO;
							
							TIM_SetCompare1(TIM1, (uint16_t)ratio_pwm);
							state=STATE_CHARGEFINISH;
							cause_exit=4;
						}
					}
					break;
				
				case STATE_CALIBRATION:
					if (mesure_vbat >= VOLTAGE_FASTCHARGE)
						{
							if (ratio_pwm > MIN_RATIO) ratio_pwm--;
						}
						else
						{
							if (ratio_pwm< MAX_RATIO) ratio_pwm ++;
						}
					break;
				
				case STATE_CHARGEFINISH:
				default:
									
					if (mesure_vbat<=VOLTAGE_IDLE) 
					{
						tempo_chargefinish++;
						
						if (tempo_chargefinish >= TEMPO_CHARGEFINISH_MAX)	state=STATE_IDLE;
					}
					else tempo_chargefinish =0;
					
				  ratio_pwm = MIN_RATIO;
				  
					break;
			}
			
			TIM_SetCompare1(TIM1, (uint16_t)ratio_pwm);

			if (count==10)
			{
				count=0;
				printf("Vbat=0x%X, Icc=0x%X, pwm=%i, state=%i\n\r",mesure_vbat, mesure_courant, ratio_pwm, state);
			}
		}
	}
	
#pragma diag_suppress 111	
	return 0;
}

/**
  * @brief  Compute mean values for current and voltage.
  * @param  current and voltage
  * @retval None
  */
char VerifyVbatFastCharge(uint32_t voltage)
{
	static uint32_t vbatarray[8];
	int i;
	uint32_t accumulator=0;
	
	for (i=1; i<8; i++)
  {
		accumulator = accumulator + vbatarray[i];
		vbatarray[i-1]=vbatarray[i];
	}
	
	vbatarray[7]=voltage;
	accumulator = accumulator+voltage;
	
	accumulator = accumulator>>3;
	
	if(accumulator>=VOLTAGE_FASTCHARGE) return 1;
	else return 0;
	
}

/**
  * @brief  Compute mean values for current and voltage.
  * @param  current and voltage
  * @retval None
  */
void GetCurrentAndVoltage(uint32_t *current, uint32_t *voltage)
{
int i;
uint32_t current_loc=0;
uint32_t voltage_loc=0;
static char firsttime=0;
static uint32_t last_current=0;
static uint32_t last_voltage=0;	

#define MINCURRENT	0x10
#define MAXCURRENT  0x2A
	
#define MINVOLTAGE	0xD0
#define MAXVOLTAGE  0x1D6

uint32_t currentmaxvar, voltagemaxvar;
	
	for (i=0; i<1024; i++)
	{
		current_loc= ADCConvertedValue[i].Current;
		voltage_loc= ADCConvertedValue[i].Voltage;
	}
	
	if (firsttime==0)
	{
		firsttime=1;
		last_current = current_loc;
		last_voltage = voltage_loc;
	}
	else
	{
		currentmaxvar=(uint32_t)((float)last_current*0.1);
		voltagemaxvar=(uint32_t)((float)last_voltage*0.05);
		
		if(currentmaxvar<MINCURRENT) currentmaxvar=MINCURRENT;
		if(currentmaxvar>MAXCURRENT) currentmaxvar=MAXCURRENT;
		
		if(voltagemaxvar<MINVOLTAGE) voltagemaxvar=MINVOLTAGE;
		if(voltagemaxvar>MAXVOLTAGE) voltagemaxvar=MAXVOLTAGE;
		
		if (current_loc>last_current)
		{
			if((current_loc-last_current)>currentmaxvar) current_loc = last_current+currentmaxvar;
		}
		else
		{
			if((last_current-current_loc)>currentmaxvar) current_loc = last_current-currentmaxvar;
		}
		
		if (voltage_loc>last_voltage)
		{
			if((voltage_loc-last_voltage)>voltagemaxvar) voltage_loc = last_voltage+voltagemaxvar;
		}
		else
		{
			if((last_voltage-voltage_loc)>voltagemaxvar) voltage_loc = last_voltage-voltagemaxvar;
		}
		
		last_current = current_loc;
		last_voltage = voltage_loc;
	}
	
	*current=current_loc;
	*voltage=voltage_loc;
}

/**
  * @brief  Configures the different system clocks.
  * @param  None
  * @retval None
  */
void RCC_Configuration(void)
{
	/* DMA clock enable */
	RCC_AHBPeriphClockCmd(RCC_AHBPeriph_DMA1, ENABLE);
	
  /* GPIOA and GPIOB clock enable */
  RCC_APB2PeriphClockCmd(RCC_APB2Periph_GPIOA | RCC_APB2Periph_ADC1 | RCC_APB2Periph_TIM1 |
                         RCC_APB2Periph_GPIOB | RCC_APB2Periph_AFIO, ENABLE);
}

void SysTick_Handler(void)
{
	static int i=0;
	static int flipflop=0;
	
	i++;
	tick=1;
	
	if (i==10)
	{
		if (state==STATE_FASTCHARGE || state == STATE_SLOWCHARGE)
		{
			if (flipflop==0) 
			{
				SetLedOn();
				flipflop=1;
			}
			else
			{
				SetLedOff();
				flipflop=0;
			}
		}
		else if (state==STATE_CHARGEFINISH) 
		{
			SetLedOn();
			flipflop=0;
		}
		else
		{
			SetLedOff();
			flipflop=0;
		}
		
		i=0;
	}
}

void SetLedOn(void)
{
	GPIO_SetBits(GPIOB, GPIO_Pin_12);
}

void SetLedOff(void)
{
	GPIO_ResetBits(GPIOB, GPIO_Pin_12);
}

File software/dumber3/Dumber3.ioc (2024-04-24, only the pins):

Mcu.UserName=STM32L071CBTx
PA0.GPIO_Label=BATTERY_SENSE
PA0.Signal=ADC_IN0
PA1.GPIO_Label=ENC_PHA_GAUCHE
PA1.Signal=GPIO_Input
PA10.GPIO_Label=XBEE_RESET
PA10.Signal=GPIO_Output
PA11.GPIO_Label=LED_SEG_F
PA11.Signal=GPIO_Output
PA12.GPIO_Label=LED_SEG_G
PA12.Signal=GPIO_Output
PA13.Signal=SYS_SWDIO
PA14.Signal=SYS_SWCLK
PA15.GPIO_Label=LED_SEG_DP
PA15.Signal=GPIO_Output
PA2.GPIO_Label=ENC_PHA_DROIT
PA2.Signal=S_TIM21_CH1
PA5.GPIO_Label=ENC_PHB_GAUCHE
PA5.Signal=S_TIM2_CH1
PA6.GPIO_Label=PWM_B_GAUCHE
PA6.Signal=S_TIM3_CH1
PA7.GPIO_Label=PWM_A_GAUCHE
PA7.Signal=S_TIM3_CH2
PA8.GPIO_Label=LED_SEG_D
PA8.Signal=GPIO_Output
PA9.GPIO_Label=LED_SEG_E
PA9.Signal=GPIO_Output
PB0.GPIO_Label=PWM_A_DROIT
PB0.Signal=S_TIM3_CH3
PB1.GPIO_Label=PWM_B_DROIT
PB1.Signal=S_TIM3_CH4
PB10.GPIO_Label=USART_TX
PB10.Signal=LPUART1_TX
PB11.GPIO_Label=USART_RX
PB11.Signal=LPUART1_RX
PB12.GPIO_Label=LED_SEG_A
PB12.Signal=GPIO_Output
PB13.GPIO_Label=LED_SEG_B
PB13.Signal=GPIO_Output
PB14.GPIO_Label=LED_SEG_C
PB14.Signal=GPIO_Output
PB15.GPIO_Label=SHUTDOWN_ENCODERS
PB15.Signal=GPIO_Output
PB3.GPIO_Label=BUTTON_SENSE
PB3.Signal=GPXTI3
PB4.GPIO_Label=USB_SENSE
PB4.Signal=GPXTI4
PB6.GPIO_Label=CHARGER_ST2
PB6.Signal=GPIO_Input
PB7.GPIO_Label=CHARGER_ST1
PB7.Signal=GPIO_Input
PB8.GPIO_Label=SHUTDOWN_5V
PB8.Signal=GPIO_Output
PB9.GPIO_Label=SHUTDOWN
PB9.Signal=GPIO_Output

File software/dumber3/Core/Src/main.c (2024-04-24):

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
/* Includes ------------------------------------------------------------------*/
#include "main.h"
#include "cmsis_os.h"

/* USER CODE BEGIN Includes */
#include "application.h"

#ifdef TESTS
#include "tests.h"
#endif /* TESTS */

/* USER CODE END Includes */

ADC_HandleTypeDef hadc;

UART_HandleTypeDef hlpuart1;

TIM_HandleTypeDef htim2;
TIM_HandleTypeDef htim3;
TIM_HandleTypeDef htim21;

/* Definitions for defaultTask */
osThreadId_t defaultTaskHandle;
const osThreadAttr_t defaultTask_attributes = {
  .name = "defaultTask",
  .stack_size = 128 * 4,
  .priority = (osPriority_t) osPriorityNormal,
};
void SystemClock_Config(void);
static void MX_GPIO_Init(void);
static void MX_LPUART1_UART_Init(void);
static void MX_TIM2_Init(void);
static void MX_TIM3_Init(void);
static void MX_TIM21_Init(void);
static void MX_ADC_Init(void);
void StartDefaultTask(void *argument);

/**
  * @brief  The application entry point.
  * @retval int
  */
int main(void)
{
  /* MCU Configuration--------------------------------------------------------*/

  /* Reset of all peripherals, Initializes the Flash interface and the Systick. */
  HAL_Init();

  /* Configure the system clock */
  SystemClock_Config();

  /* Initialize all configured peripherals */
  MX_GPIO_Init();
  MX_LPUART1_UART_Init();
  MX_TIM2_Init();
  MX_TIM3_Init();
  MX_TIM21_Init();
  MX_ADC_Init();
  /* USER CODE BEGIN 2 */
#ifdef TESTS
  TESTS_Init();
#else
  APPLICATION_Init();
#endif /* TESTS */
  /* USER CODE END 2 */

  /* Init scheduler */
  osKernelInitialize();

  /* USER CODE BEGIN RTOS_MUTEX */
	/* add mutexes, ... */
  /* USER CODE END RTOS_MUTEX */

  /* USER CODE BEGIN RTOS_SEMAPHORES */
	/* add semaphores, ... */
  /* USER CODE END RTOS_SEMAPHORES */

  /* USER CODE BEGIN RTOS_TIMERS */
	/* start timers, add new ones, ... */
  /* USER CODE END RTOS_TIMERS */

  /* USER CODE BEGIN RTOS_QUEUES */
	/* add queues, ... */
  /* USER CODE END RTOS_QUEUES */

  /* Create the thread(s) */
  /* creation of defaultTask */
  defaultTaskHandle = osThreadNew(StartDefaultTask, NULL, &defaultTask_attributes);

  /* USER CODE BEGIN RTOS_THREADS */
	/* add threads, ... */

  /* USER CODE END RTOS_THREADS */

  /* USER CODE BEGIN RTOS_EVENTS */
	/* add events, ... */
  /* USER CODE END RTOS_EVENTS */

  /* Start scheduler */
  osKernelStart();

  /* We should never get here as control is now taken by the scheduler */
  /* Infinite loop */
  /* USER CODE BEGIN WHILE */
	while (1)
	{
    /* USER CODE END WHILE */

    /* USER CODE BEGIN 3 */
	}
  /* USER CODE END 3 */
}

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
/* USER CODE BEGIN 4 */
TickType_t msToTicks(TickType_t ms) {
	TickType_t tmp = ms;

	if (ms<(1000/configTICK_RATE_HZ))
		tmp = 1;
	else {
		tmp = ms/(1000/configTICK_RATE_HZ);

		if (ms % (1000/configTICK_RATE_HZ)) // if the delay is not true multiple of tick rate, increase by one (delay longer)
			tmp ++;
	}
	return tmp;
}
/* USER CODE END 4 */

/* USER CODE BEGIN Header_StartDefaultTask */
/**
 * @brief  Function implementing the defaultTask thread.
 * @param  argument: Not used
 * @retval None
 */
/* USER CODE END Header_StartDefaultTask */
void StartDefaultTask(void *argument)
{
  /* USER CODE BEGIN 5 */
//	LEDS_State state = leds_off;
//
//	/* Infinite loop */
//	for(;;)
//	{
//		state++;
//		MESSAGE_SendMailbox(LEDS_Mailbox, MSG_ID_LED_ETAT, SEQUENCEUR_Mailbox, (void*)&state);
//
//		if (state>leds_erreur)
//			state = leds_off;
//
//		vTaskDelay(pdMS_TO_TICKS(5000));
//	}
  /* USER CODE END 5 */
}

/**
  * @brief  Period elapsed callback in non blocking mode
  * @note   This function is called  when TIM6 interrupt took place, inside
  * HAL_TIM_IRQHandler(). It makes a direct call to HAL_IncTick() to increment
  * a global variable "uwTick" used as application time base.
  * @param  htim : TIM handle
  * @retval None
  */
void HAL_TIM_PeriodElapsedCallback(TIM_HandleTypeDef *htim)
{
  if (htim->Instance == TIM6) {
    HAL_IncTick();
  }
  /* USER CODE BEGIN Callback 1 */
  else if ((htim->Instance == TIM2) || (htim->Instance == TIM21))
		  MOTORS_TimerEncodeurUpdate (htim);
  /* USER CODE END Callback 1 */
}

/**
  * @brief  This function is executed in case of error occurrence.
  * @retval None
  */
void Error_Handler(void)
{
  /* USER CODE BEGIN Error_Handler_Debug */
	/* User can add his own implementation to report the HAL error return state */
	__disable_irq();
	while (1)
	{
	}
  /* USER CODE END Error_Handler_Debug */
}

#ifdef  USE_FULL_ASSERT
/**
  * @brief  Reports the name of the source file and the source line number
  *         where the assert_param error has occurred.
  * @param  file: pointer to the source file name
  * @param  line: assert_param error line source number
  * @retval None
  */
void assert_failed(uint8_t *file, uint32_t line)
{
  /* USER CODE BEGIN 6 */
	/* User can add his own implementation to report the file name and line number,
     ex: printf("Wrong parameters value: file %s on line %d\r\n", file, line) */
  /* USER CODE END 6 */
}
#endif /* USE_FULL_ASSERT */

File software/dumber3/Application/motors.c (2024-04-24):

/**
 ******************************************************************************
 * @file motors.c
 * @brief motors driver body
 * @author S. DI MERCURIO (dimercur@insa-toulouse.fr)
 * @date December 2023
 *
 ******************************************************************************
 * @copyright Copyright 2023 INSA-GEI, Toulouse, France. All rights reserved.
 * @copyright This project is released under the Lesser GNU Public License (LGPL-3.0-only).
 *
 * @copyright This file is part of "Dumber" project
 *
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
 ******************************************************************************
 */

#include "motors.h"
#include "timers.h"

#include "stm32l0xx_ll_gpio.h"
#include "stm32l0xx_ll_tim.h"

#include <limits.h>

/** @addtogroup Application_Software
  * @{
  */

/** @addtogroup MOTORS
 * Motors driver is in charge of controlling motors and applying a regulation to ensure a linear trajectory
 *
 * Global informations about peripherals
 * - Main clock: 6 Mhz
 * - TIM2 PWM Input (CH1): right encoder PHB : 0 -> 65535
 * - TIM21 PWM Input (CH1): left encoder PHA: 0 -> 65535
 * - TIM3: PWM Output motor (0->200) (~30 Khz)
 * @{
 */

/** @addtogroup MOTORS_Private Private
 * @{
 */

extern TIM_HandleTypeDef htim2;
extern TIM_HandleTypeDef htim21;
extern TIM_HandleTypeDef htim3;

#define MOTORS_MAX_COMMAND	200
#define MOTORS_MAX_ENCODER	USHRT_MAX

/** Structure for storing motors (left or right) control state
 * Used during control loop task for controlling motor
 */
typedef struct {
	int16_t output; 		/**< Output value to send to motor. Positive values for forward and negative values for backward
	                             +/- 65535 for full power and 0 for motor stop */
	int16_t setpoint;		/**< Set point value for motor control*/
	uint16_t encoder;		/**< Number of encoder pulse acquired between last control loop iteration*/
	uint16_t encoderEdge;	/**< Delta T between two encoders pulse (the fastest the motor goes, the lowest the value is.
	                             65536 means motor is stopped */
	uint8_t slowMotor;		/**< Flag for indicating that motor has stopped */
} MOTORS_MotorState;

/** Structure for storing differential control state.
 * Used during top differentiel control loop, to ensure trjactory is strait */
typedef struct {
	uint8_t type;			/**< not used */
	int16_t output;			/**< not used */
	int16_t setpoint;		/**< not used */
	int32_t distance;		/**< Distance to move on */
	int32_t turns;			/**< Number of turns to apply */
} MOTORS_DifferentialState;

MOTORS_MotorState MOTORS_LeftMotorState, MOTORS_RightMotorState = { 0 };
MOTORS_DifferentialState MOTORS_DiffState = { 0 };

/**
 * Proportionnal constant for motor control loop
 */
#define MOTOR_Kp 		300

/***** Tasks part *****/

/* Tache moteurs (gestion des messages) */
StaticTask_t xTaskMotors;
StackType_t xStackMotors[STACK_SIZE];
TaskHandle_t xHandleMotors = NULL;
void MOTORS_HandlerTask(void *params);

/* Tache moteurs périodique (asservissement) */
StaticTask_t xTaskMotorsControl;
StackType_t xStackMotorsControl[STACK_SIZE];
TaskHandle_t xHandleMotorsControl = NULL;
void MOTORS_ControlTask(void *params);

/* Fonctions diverses */
void MOTORS_Set(int16_t leftMotor, int16_t rightMotor);
void MOTORS_PowerOff(void);
void MOTORS_PowerOn(void);
int16_t MOTORS_EncoderCorrection(MOTORS_MotorState state);

#ifdef TESTS
TIM_HandleTypeDef htim7;

volatile uint32_t DEBUG_startTime = 0;
volatile uint32_t DEBUG_endTime = 0;
volatile uint32_t DEBUG_duration = 0;
volatile uint32_t DEBUG_worstCase = 0;

void Init_Systick(void) {
//	TIM_ClockConfigTypeDef sClockSourceConfig = { 0 };
//
//	__HAL_RCC_TIM7_CLK_ENABLE();
//
//	htim7.Instance = TIM2;
//	htim7.Init.Prescaler = 0;
//	htim7.Init.CounterMode = TIM_COUNTERMODE_UP;
//	htim7.Init.Period = 65535;
//	htim7.Init.ClockDivision = TIM_CLOCKDIVISION_DIV1;
//	htim7.Init.AutoReloadPreload = TIM_AUTORELOAD_PRELOAD_DISABLE;
//	if (HAL_TIM_Base_Init(&htim7) != HAL_OK) {
//		Error_Handler();
//	}
//
//	sClockSourceConfig.ClockSource = TIM_CLOCKSOURCE_INTERNAL;
//	if (HAL_TIM_ConfigClockSource(&htim7, &sClockSourceConfig) != HAL_OK) {
//		Error_Handler();
//	}
//
//	LL_TIM_EnableCounter(TIM7);
}

void StartMeasure(void) {
//	DEBUG_startTime = LL_TIM_GetCounter(TIM7);
}

void EndMeasure(void) {
//	DEBUG_endTime = LL_TIM_GetCounter(TIM7);
//
//	if (DEBUG_startTime >= DEBUG_endTime)
//		DEBUG_duration = 65533 - DEBUG_startTime + DEBUG_endTime;
//	else
//		DEBUG_duration = DEBUG_endTime - DEBUG_startTime;
//
//	if (DEBUG_duration > DEBUG_worstCase)
//		DEBUG_worstCase = DEBUG_duration;
}
#endif /* TESTS */

/**
 * @brief  Function for initializing motors driver
 *
 * @param  None
 * @return None
 */
void MOTORS_Init(void) {
	/* Désactive les alimentations des moteurs */
	MOTORS_PowerOff();

	/* Create the task without using any dynamic memory allocation. */
	xHandleMotors = xTaskCreateStatic(MOTORS_HandlerTask, /* Function that implements the task. */
			"MOTORS Handler", /* Text name for the task. */
			STACK_SIZE, /* Number of indexes in the xStack array. */
			NULL, /* Parameter passed into the task. */
			PriorityMotorsHandler,/* Priority at which the task is created. */
			xStackMotors, /* Array to use as the task's stack. */
			&xTaskMotors); /* Variable to hold the task's data structure. */
	vTaskResume(xHandleMotors);

	/* Create the task without using any dynamic memory allocation. */
	xHandleMotorsControl = xTaskCreateStatic(
			MOTORS_ControlTask, /* Function that implements the task. */
			"MOTORS Control", /* Text name for the task. */
			STACK_SIZE, /* Number of indexes in the xStack array. */
			NULL, /* Parameter passed into the task. */
			PriorityMotorsAsservissement,/* Priority at which the task is created. */
			xStackMotorsControl, /* Array to use as the task's stack. */
			&xTaskMotorsControl); /* Variable to hold the task's data structure. */
	vTaskSuspend(xHandleMotorsControl); // On ne lance la tache d'asservissement que lorsque'une commande moteur arrive

	MOTORS_PowerOff();

#ifdef TESTS
	Init_Systick();
#endif /* TESTS */
}

/**
 * @brief  Request a movment in strait line
 *
 * @remark This function wrap a message sending to motors mailbox.
 *         In case of multiple call, only last one will be applied,
 *         with potentially some spurious movement when processing previous messages
 *
 * @param[in] distance Distance to move on, in mm.
 *            Positive values for forward movements and negative values for backward movements
 * @return None
 */
void MOTORS_Move(int32_t distance) {
	static int32_t dist;

	dist = distance*15;

	if (dist) {
		MOTORS_PowerOn();
		MESSAGE_SendMailbox(MOTORS_Mailbox, MSG_ID_MOTORS_MOVE,
				APPLICATION_Mailbox, (void*) &dist);
	} else
		MOTORS_Stop();
}
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

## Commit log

2024-04-24 Add initial project from INSA-GEI/dumber
    [0605-LED_Verde.STEP, 2.54_straight-header.SLDASM, 2.54_straight-pin.SLDPRT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]
2024-04-24 Change to branch dumber-v3
    [0605-LED_Verde.STEP, 1593K PCB.dwg, 1593K PCB.igs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]

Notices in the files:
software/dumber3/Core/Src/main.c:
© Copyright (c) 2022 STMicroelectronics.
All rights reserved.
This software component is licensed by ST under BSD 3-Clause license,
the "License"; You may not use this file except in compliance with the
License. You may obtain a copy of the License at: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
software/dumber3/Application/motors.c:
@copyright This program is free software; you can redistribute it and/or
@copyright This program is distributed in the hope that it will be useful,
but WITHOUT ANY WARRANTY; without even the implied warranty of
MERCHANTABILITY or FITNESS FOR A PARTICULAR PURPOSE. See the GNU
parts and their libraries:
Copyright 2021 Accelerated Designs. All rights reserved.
